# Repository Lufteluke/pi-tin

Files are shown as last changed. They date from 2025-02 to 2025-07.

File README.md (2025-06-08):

# Pi Tin

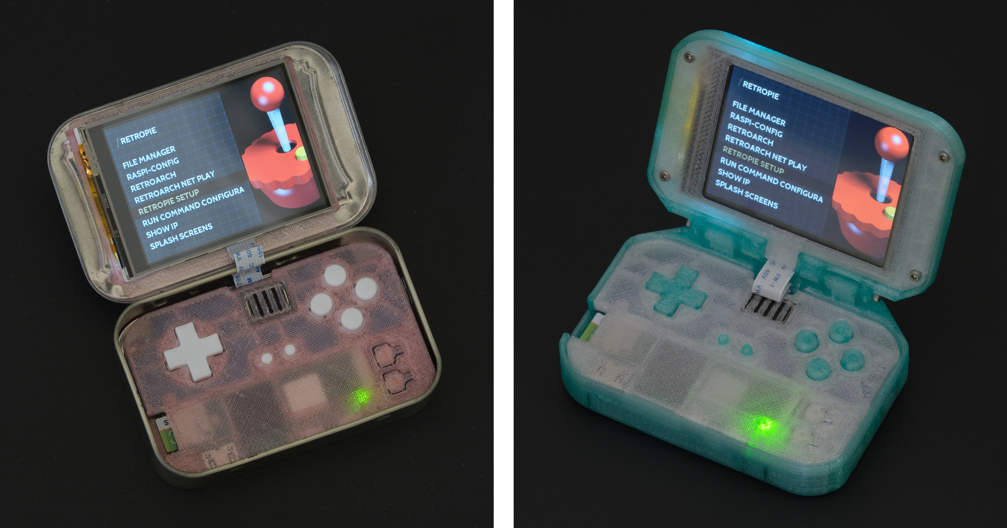
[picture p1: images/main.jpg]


Pi Tin is an open source retro gaming device designed around the Raspberry Pi Zero 2 W and a 2.8" 320x240 TFT display, the largest readily available size that will fit into an Altoids tin. The Pi Zero 2 W is capable of emulating most SNES, GBA, PS1, Genesis/Megadrive, and even some N64 games.

Pi Tin's gamepad uses the exact same Alps tactile switches and elastomer membrane design used in the Gameboy Advance SP and DSi to achieve superior button feel over designs using conductive rubber buttons or bare tactile switches. It features a soft power button to turn on or safely shut down the system with a single press, and is designed to be safe to use while charging and compatible with all USB-C cables and chargers. The battery lasts for up to 5 hours of gaming <small>(tested on 3D printed case option - 2000mAh battery)</small>.

Building a Pi Tin requires a Raspberry Pi Zero 2 W, two custom PCBs, some 3D printed parts, and a few other components which are readily available from distributors. The PCBs require advanced soldering skills and ideally both a hot plate and hot air station to assemble by hand. We are working on making kits with assembled PCBs available to purchase.

Shown below are Rev. 2 PCBs, manufactured by [PCBWay](https://www.pcbway.com/). PCBWay reached out to sponsor this project and I was excited to work with them as I have used PCBWay before at work and have been consistently satisfied with their customization options, turnkey parts sourcing ability, and very responsive customer support. The quality of PCBs they delivered here was excellent as always.

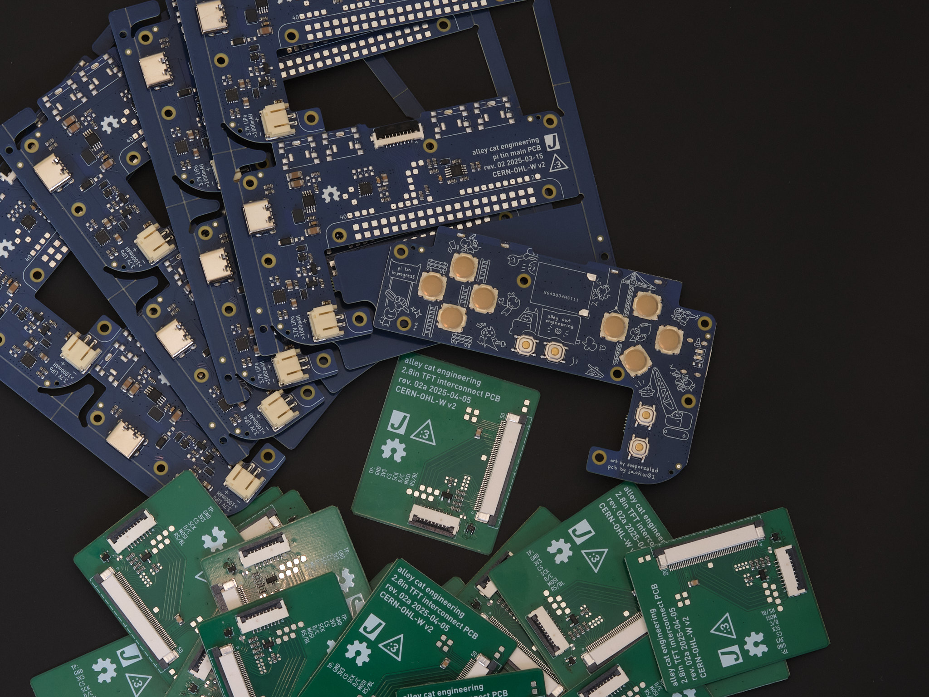
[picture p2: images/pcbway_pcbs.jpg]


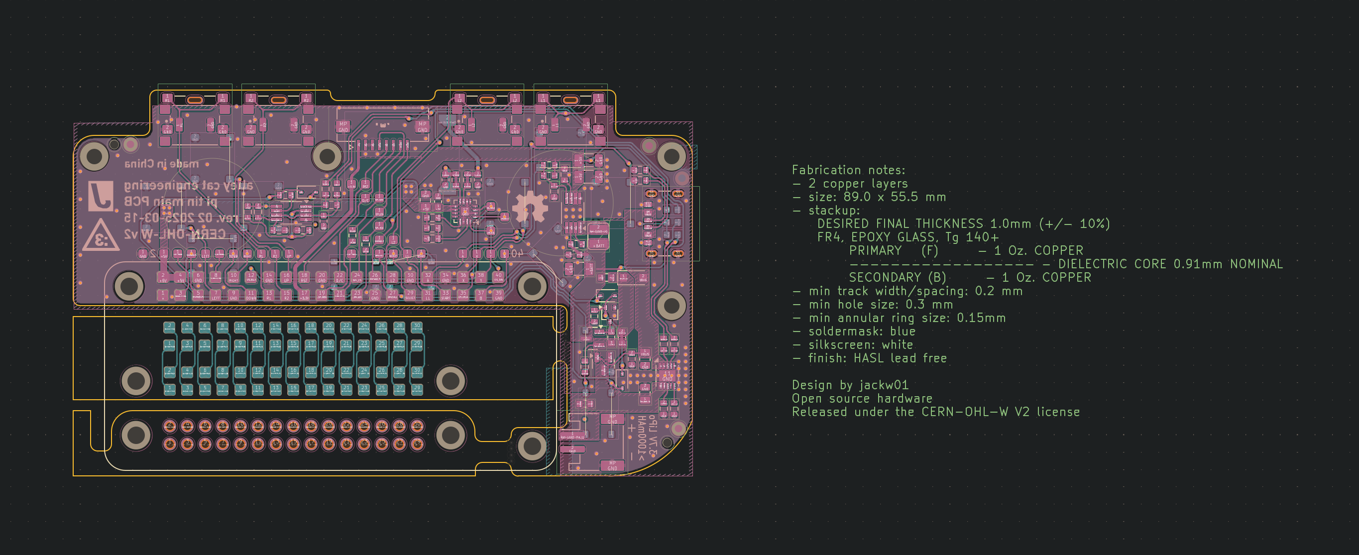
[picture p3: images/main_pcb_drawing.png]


[Main PCB Schematic as PDF (Rev. 2)](pcb_main_r2/pi_tin_main_pcb_r2.pdf)

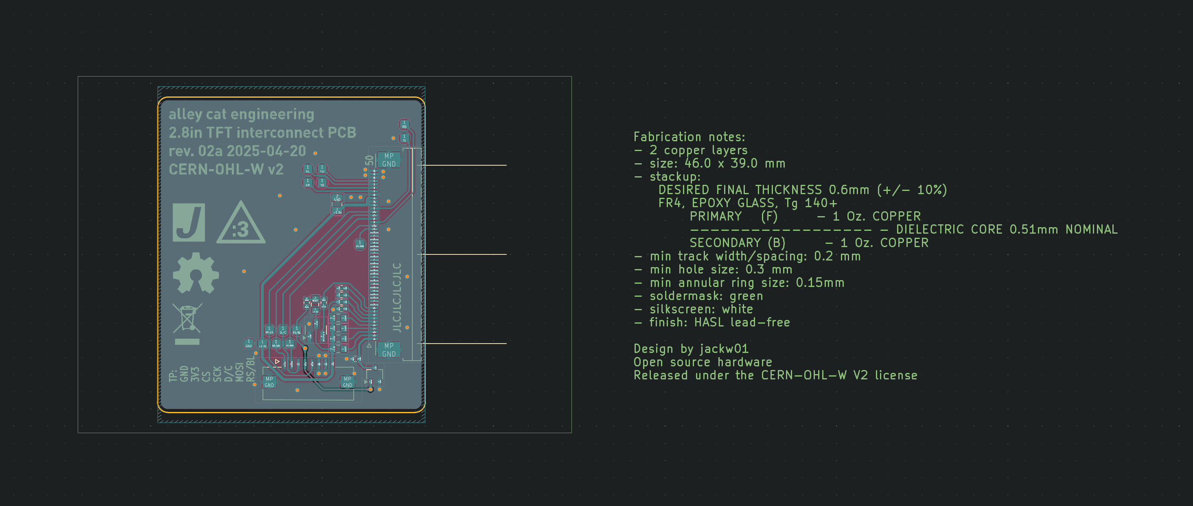
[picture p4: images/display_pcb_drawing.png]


[Display PCB Schematic as PDF (Rev. 2a)](pcb_display_r2a/pi_tin_display_pcb_r2a.pdf)

*Note 2025-06-07: Main PCB files have been updated with the practice boards included in the kits. Display PCB files have been updated to revision 2a with minor component changes and brightness control support. Previous revision files are in the old folder.*

*Note: Most other photos in this guide show Rev. 1 PCBs.*

## build options

Pi Tin can either be built with a 3D printed clamshell case (93 x 66 x 26.5mm) or built to fit inside an Altoids tin.

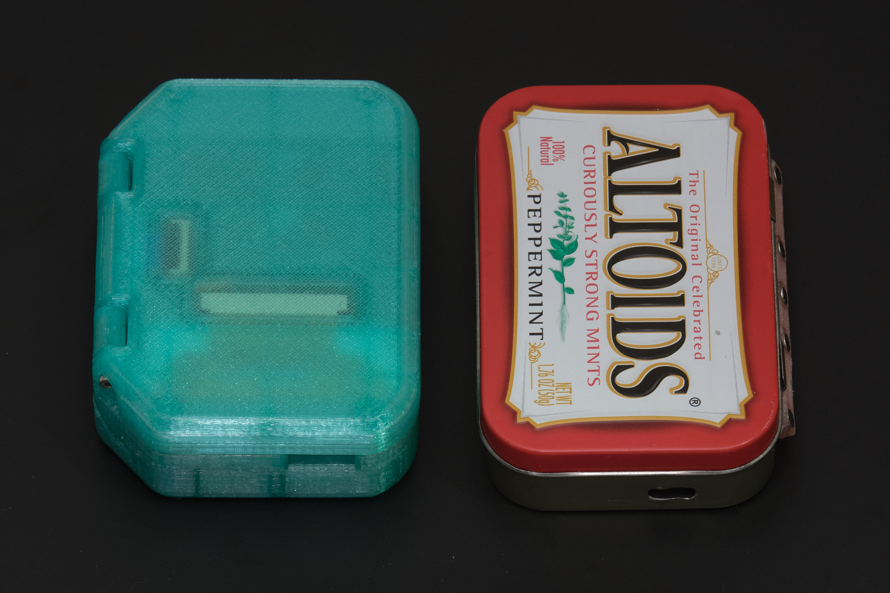
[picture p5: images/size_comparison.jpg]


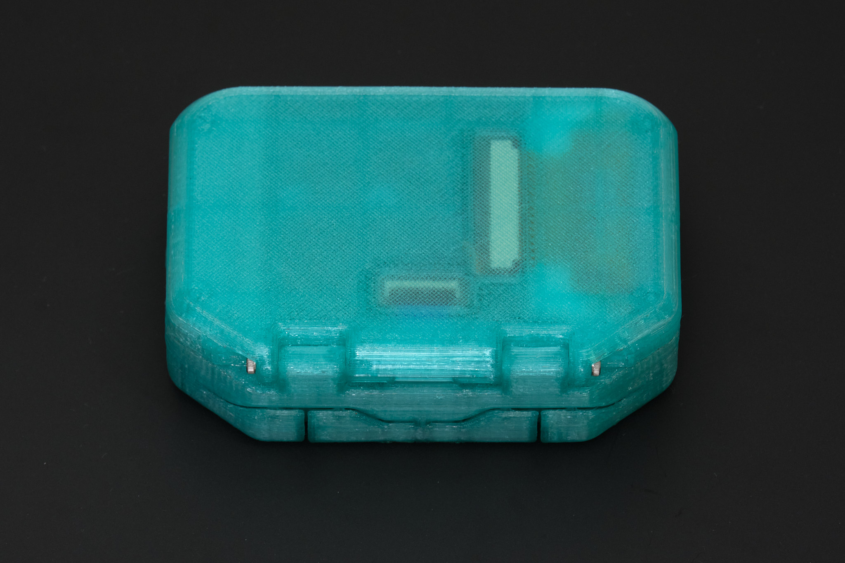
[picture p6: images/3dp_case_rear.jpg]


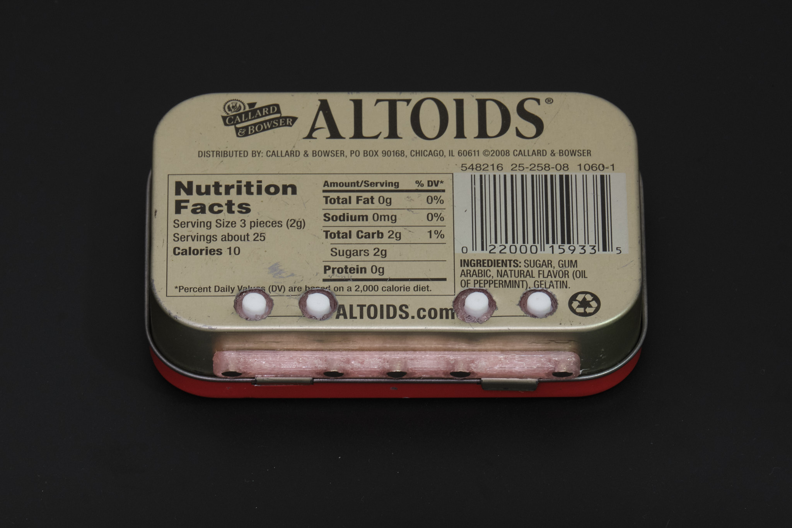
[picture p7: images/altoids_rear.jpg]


The Altoids tin build option is more difficult than the 3D printed case option; it requires additional tools and experience using them. It has poor ergonomics due to the constraints of building inside an Altoids tin and the battery capacity is 40% lower than the 3D printed case version. We strongly recommend the 3D printed case option for these reasons.

**Important: Read through all the instructions thoroughly before building. This is an intermediate level project and we don't recommend attempting it without prior electronics kit building experience.**

Build instructions for both options start with the [hardware build guide](./hardware_build).

## license

The source files for this project are located at [https://github.com/jackw01/pi-tin/](https://github.com/jackw01/pi-tin/).

The PCB schematics, layouts, and Gerber files and the 3D CAD files for this project are released under the CERN Open Hardware Licence Version 2 - Weakly Reciprocal (CERN-OHL-W V2). The files in the `software` directory are in the public domain, free of copyright restrictions. The text, photographs, and illustrations on this website may not be reproduced without permission.

## mintypi disclaimer

We are aware of the existence of MintyPi; our main motivation for building this project was that MintyPi is no longer possible to build as it relies on proprietary parts that are not sold anymore. MintyPi was a closed-source commercial product and it was not released under a license limiting or requiring attribution for derivative works. The creators did not release a schematic of the custom PCBs or even documentation of what drivers/software were installed on their prebuilt SD card image.

## legal disclaimer

Any trademarked product names found on this website belong to their respective owners; this project is in no way affiliated with or endorsed by these companies. Pi Tin is designed to run [RetroPie](https://retropie.org.uk/), which is open source software released under the GPL. The prebuilt RetroPie disk image we provide does not contain any copyrighted ROMs or games. Pi Tin is not designed to enable illegal activity; we do not condone piracy and we will not provide support to anyone looking to obtain copyrighted content. Posting requests for copyrighted ROMs or other piracy-related content on GitHub issues or discussions will result in deletion and a ban.

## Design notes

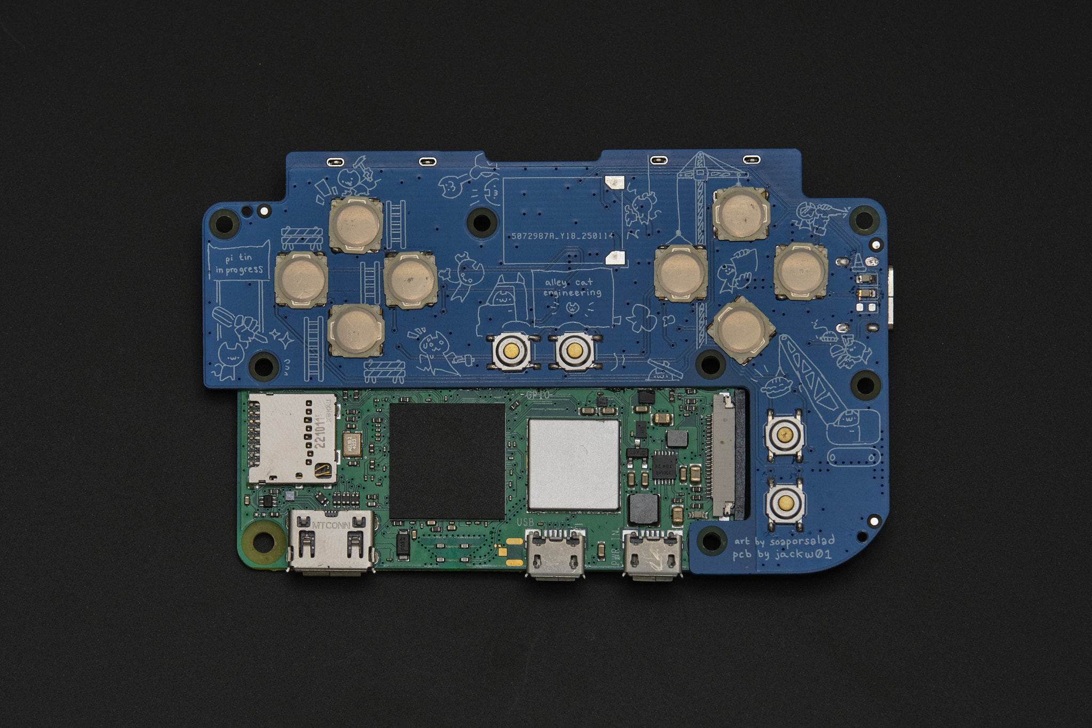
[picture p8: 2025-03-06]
images/main_pcb_1.jpg

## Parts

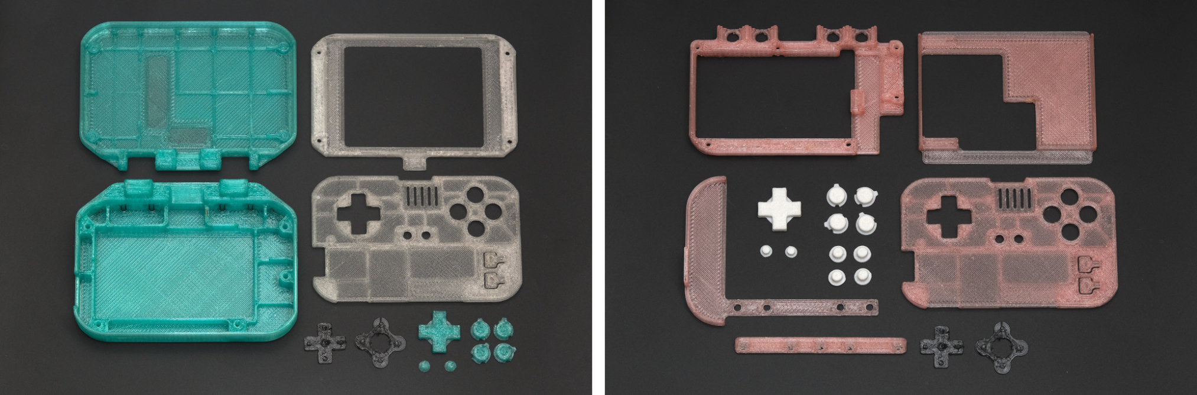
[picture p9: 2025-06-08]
images/3dp_parts.jpg

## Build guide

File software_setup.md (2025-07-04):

# Pi Tin Software Setup

For convenience, we provide a SD card image based on [RetroPie 4.8](https://retropie.org.uk/download/) with all required software installed and configured. This guide assumes you are using the prebuilt image. If not, full instructions for installing the required software on top of a clean install of RetroPie are [here](./full_software_setup).

## 1. install the prebuilt image

Download the Pi Tin prebuilt image [here (2GB zip file)](https://github.com/jackw01/pi-tin/releases/download/v1.1/pi_tin_20250617.zip). Unzip and write the image to a 8GB or larger MicroSD card using [Win32DiskImager](https://sourceforge.net/projects/win32diskimager/), [Raspberry Pi Imager](https://www.raspberrypi.com/software/), or [Etcher](https://etcher.balena.io/).

## 2. set up wifi

After writing the SD card, eject and reinsert it to access the newly created boot partition.

*Note: If using Windows, ignore any popups asking to "scan and fix" or format the SD card.*

Create a file called `wpa_supplicant.conf` in the root directory of the boot partition with the contents below, replacing `SSID` and `PASSWORD` with your network name and password. You can add multiple networks by copying the `network={}` block. If you are outside of the United States, change `country=US` to your country's [ISO two-letter country code](https://en.wikipedia.org/wiki/List_of_ISO_3166_country_codes).

```conf
country=US
ctrl_interface=DIR=/var/run/wpa_supplicant GROUP=netdev
update_config=1

# RETROPIE CONFIG START
network={
    ssid="SSID"
    psk="PASSWORD"
}
# RETROPIE CONFIG END
```

Eject the SD card.

## 3. boot Raspberry Pi and verify functionality

With the display connected, insert the SD card, connect the USB-C cable, and press the power button to power up the Raspberry Pi. If the hardware build and software installation were done correctly, the display should show a black screen at power on, then within 1 minute display the RetroPie splash screen and the EmulationStation launcher. Hold the power button for about half a second and release it. The Raspberry Pi should safely shut down and the display should turn off completely. If the Raspberry Pi does not shut down, it is likely because one or more of the pads is not soldered properly.

## 4. connect via SSH and change password

The Raspberry Pi should automatically connect to your WiFi network within a minute after booting up and you should be able to log in via SSH using the default password `raspberry` (use `ssh pi@retropie.local` in the command line on any computer running Windows 10 or 11, Mac OS, or Linux).

We strongly recommend changing the user password since SSH and SMB are enabled. This can be done by running the `passwd` command on the Raspberry Pi via SSH.

You can also test audio at this point by running `speaker-test -c2` on the Raspberry Pi. You should hear white noise from the speaker.

## 5. using RetroPie

Follow the [RetroPie Getting Started guide](https://retropie.org.uk/docs/Controller-Configuration/) to configure and test the gamepad buttons and load ROMs.

Pi Tin has a dedicated hotkey for RetroPie which is located directly above the power button. **This button should be selected as "Hotkey Enable" during the controller setup process.** The special functions shown below can be used by pressing the buttons while holding down the hotkey.

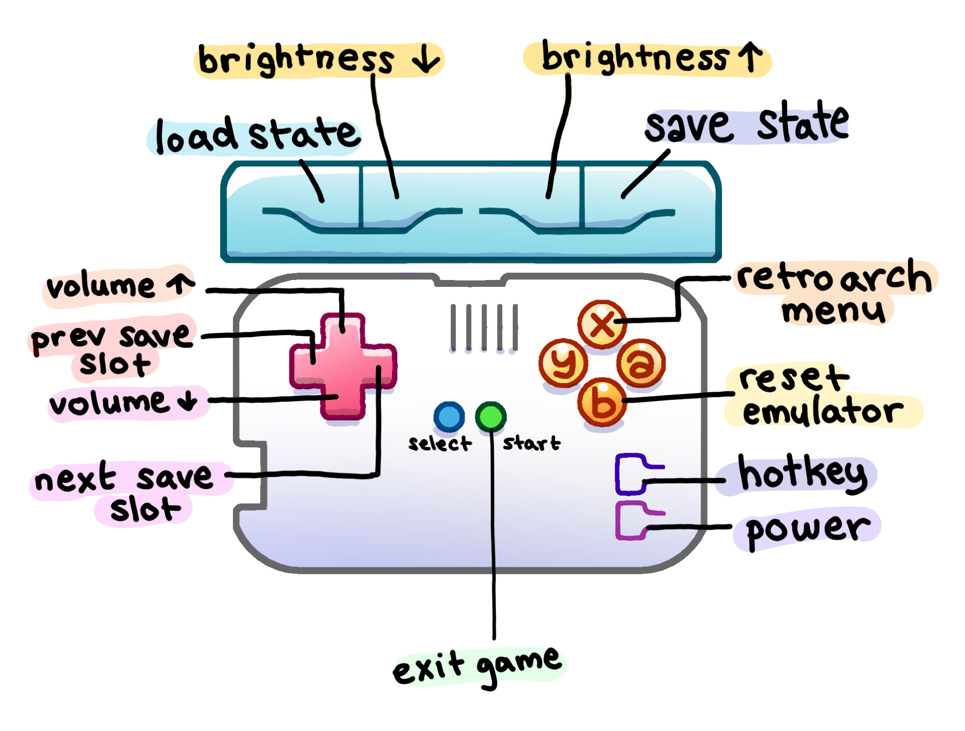
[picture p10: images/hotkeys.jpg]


### configure volume control

The volume control hotkeys must be set up after configuring the controller by manually editing the  configuration file. Log in via SSH and run `sudo nano "/opt/retropie/configs/all/retroarch/autoconfig/GPIOnext Joypad 1.cfg"`. Add these lines at the end of the file to enable volume control using the hotkey and press `Ctrl+X`, then `Y`, then `Enter` to save.

```conf
input_volume_up_axis = "-1"
input_volume_down_axis = "+1"
```

## next steps

Once you have installed and configured RetroPie and verified that the hardware is working, continue to the final assembly guide for your build option.

- [final assembly - 3D printed case version](./3dp_assembly)
- [final assembly - Altoids tin version](./altoids_assembly)

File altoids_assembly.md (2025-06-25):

# Pi Tin Final Assembly (Altoids Tin Version)

**Important: Clean surfaces with isopropyl alcohol before using glue or double-sided tape.**

## 1. complete the Main PCB assembly

Insert three 4x2mm neodymium disc magnets into the rear housing as shown, applying a small dab of cyanoacrylate glue to hold each one in place.

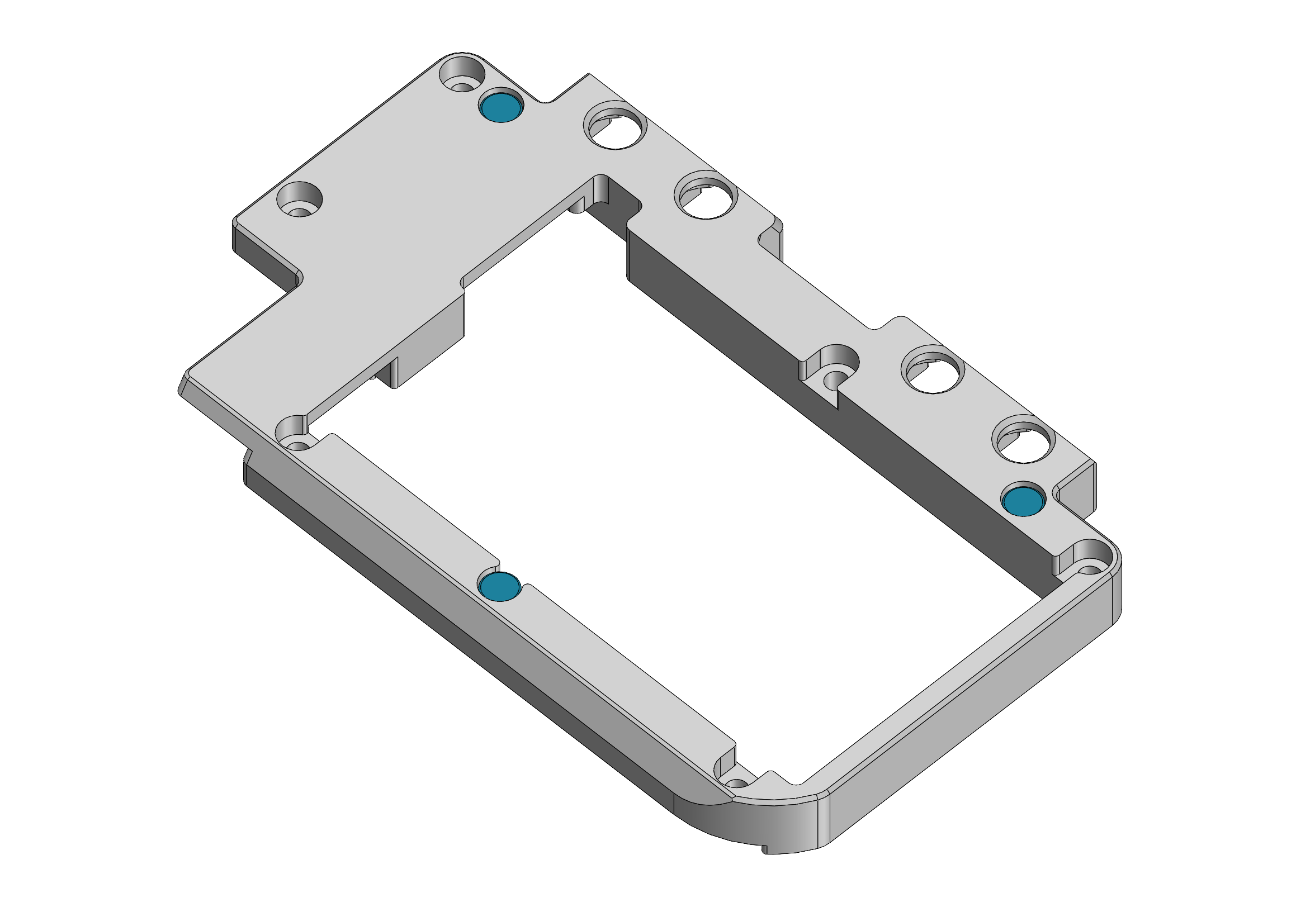
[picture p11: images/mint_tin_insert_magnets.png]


Place the Main PCB onto the assembled front panel and connect the battery, leaving a loop in the battery wires.

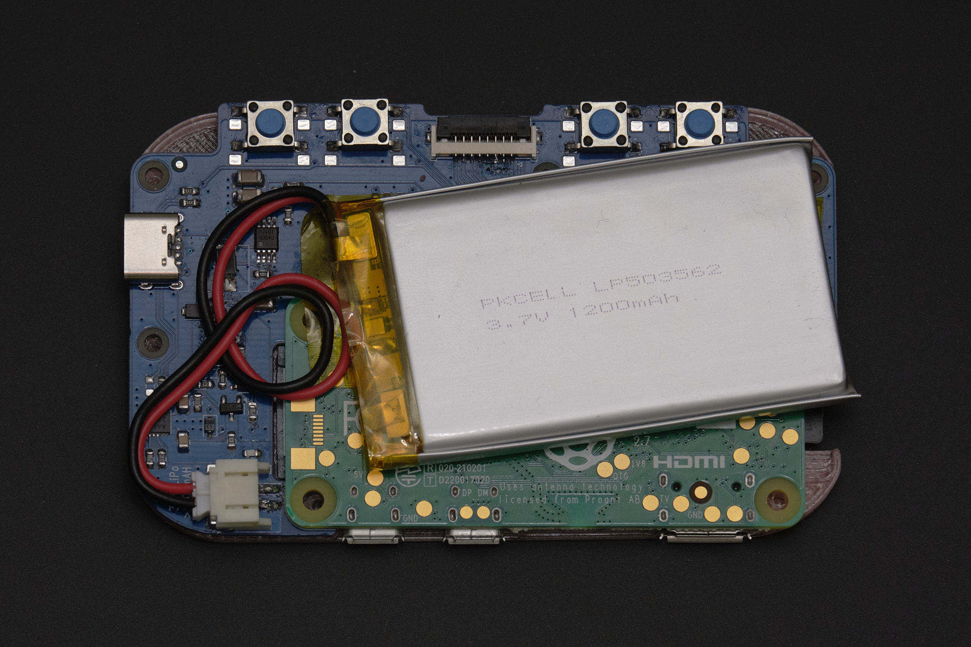
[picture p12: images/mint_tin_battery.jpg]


Insert the four rear buttons into the rear housing, then pick up the front panel and Main PCB together and mate them with the rear housing. The components should fit together closely without applying any force and the battery wires must not be pinched between the rear housing and PCB. Insert six M2x8mm socket head cap screws into the counterbore holes on the rear housing and tighten them in a star pattern. Do not overtighten the screws - stop tightening as soon as no gap is visible between the 3D printed parts and the PCB.

*Note: Some downward pressure is required when tightening the screws for the first time since they are threading directly into plastic.*

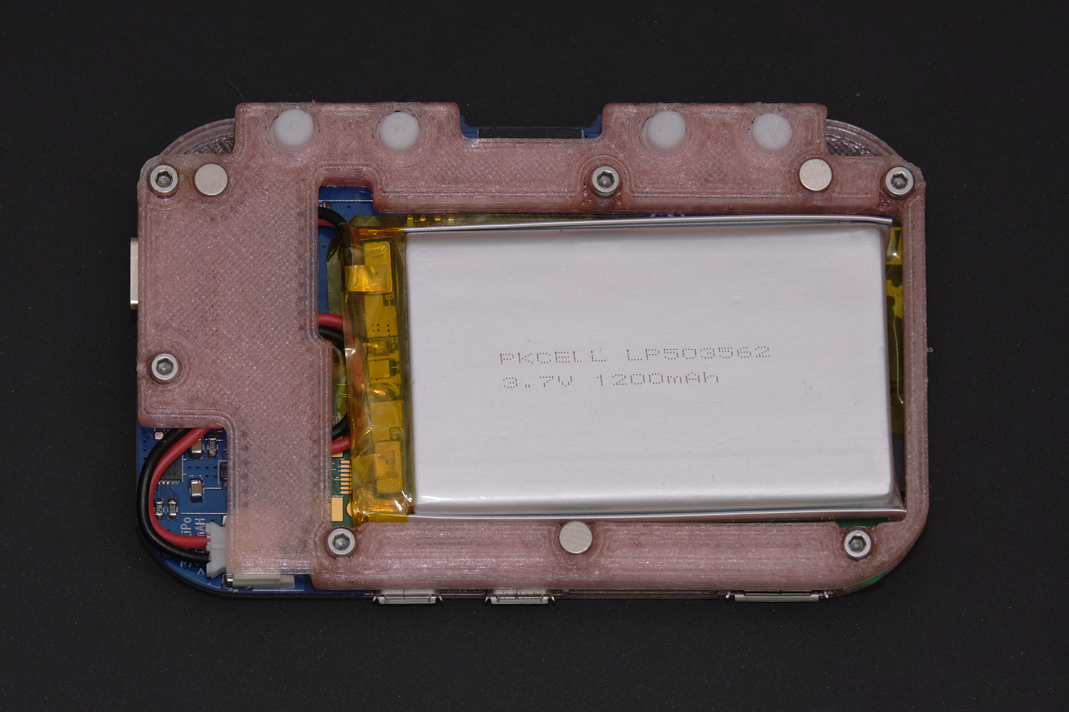
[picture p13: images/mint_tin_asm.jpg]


Check that the buttons on the front panel are not sticking. If they are, it is likely due to misalignment of the 3D printed membrane or defects on the 3D printed parts that need to be trimmed off.

Apply two 6x10mm pieces and one 18x10mm piece of EPDM foam tape in the locations highlighted in blue below to cushion the battery and keep the assembly centered inside the mint tin.

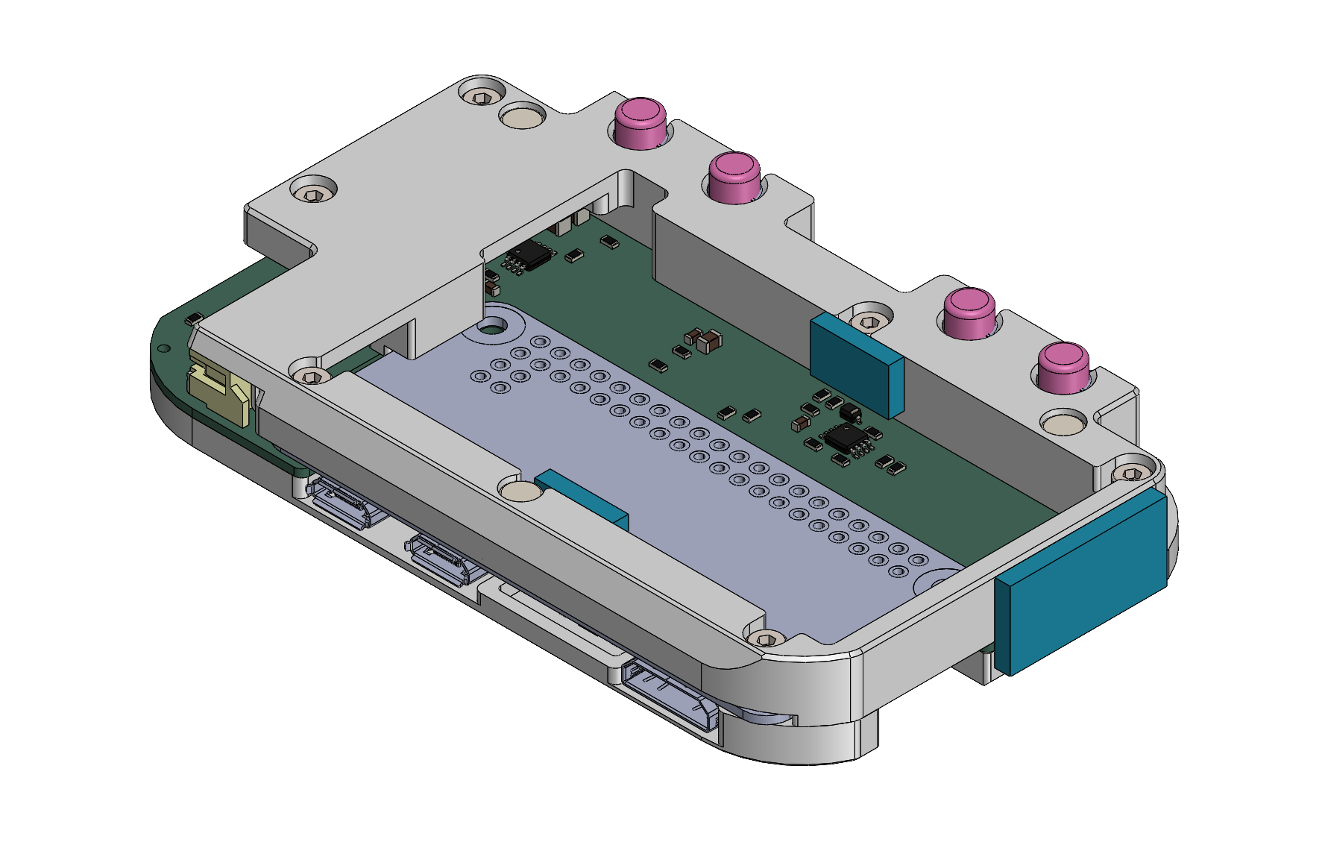
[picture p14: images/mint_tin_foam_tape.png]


## 2. prepare the Altoids tin

Align the drill guide with the tin as shown and use it to mark locations for drilling holes for the USB port and rear buttons. Mark the center of the holes using a center punch or scribe. Use caution if using an automatic center punch as it will leave large dents in the tin if nothing is placed on the other side of the thin metal.

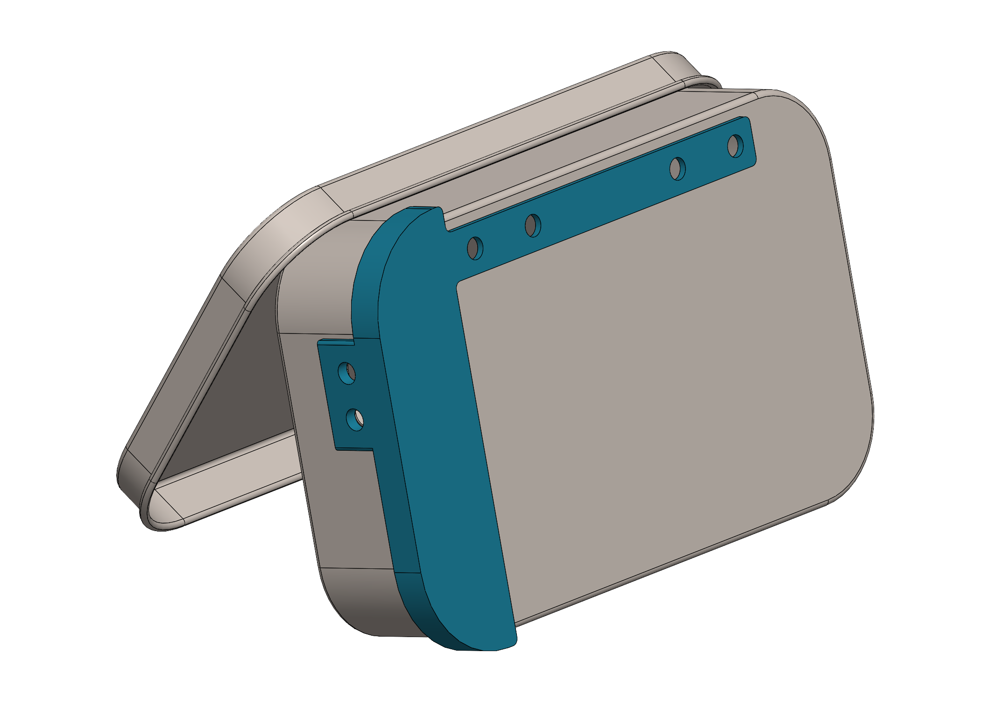
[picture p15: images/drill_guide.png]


Drill all holes with a 1/16in (1.5mm) drill bit. Drill out the four rear button holes to 3/16in (5mm), gradually increasing drill bit sizes and using a sacrificial piece of wood on the other side of the tin to keep the metal from tearing. Drill out the two holes forming the USB port cutout to 1/8in (3mm). Use flush wire cutters to cut out the remaining tab of metal between the holes. Using needle files or a rotary tool, file the USB port cutout to its final shape and debur the edges of the other holes.

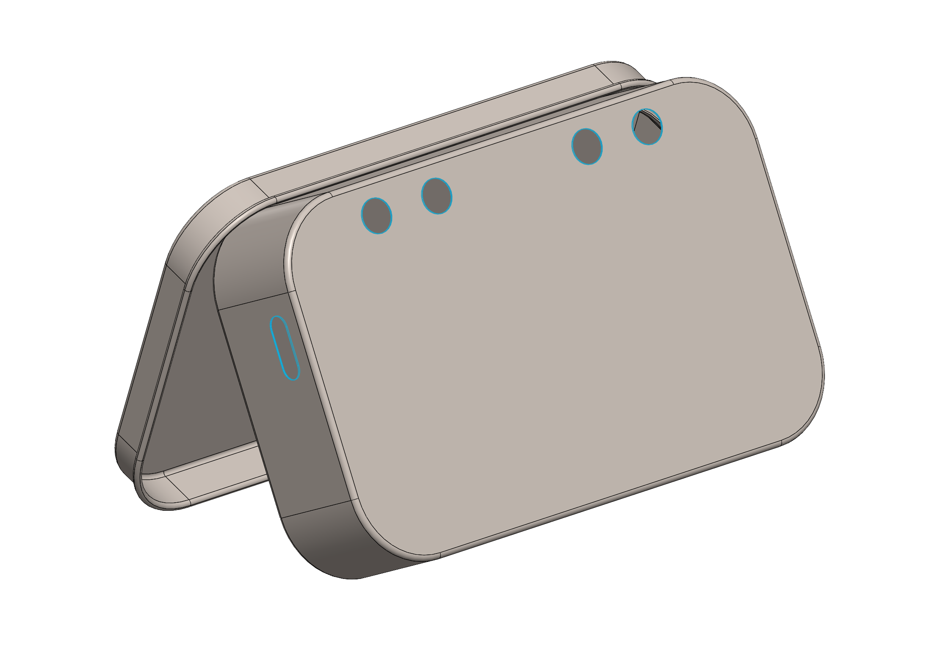
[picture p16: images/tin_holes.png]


Thoroughly clean the tin to remove any metal shavings.

## 3. install the lid stop

Attach the lid stop to the tin as shown using cyanoacrylate glue.

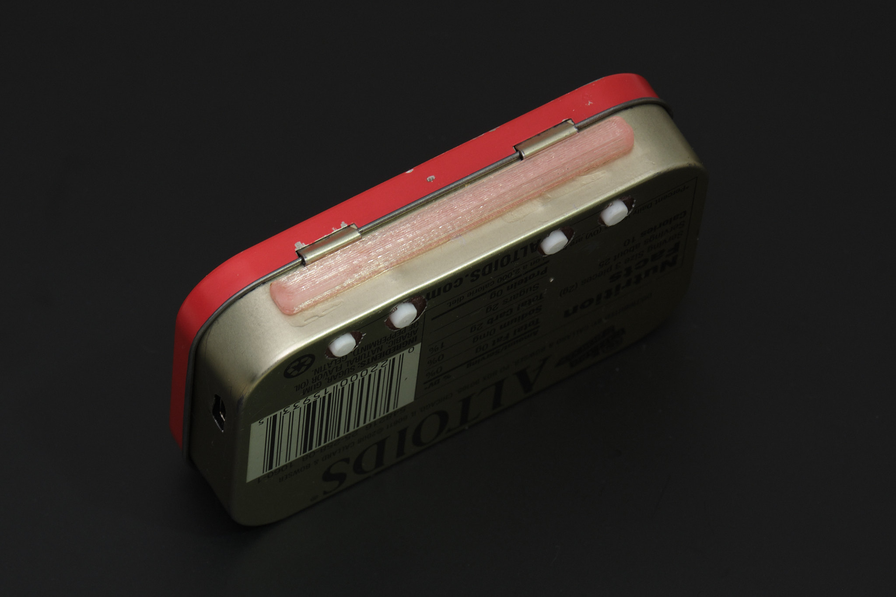
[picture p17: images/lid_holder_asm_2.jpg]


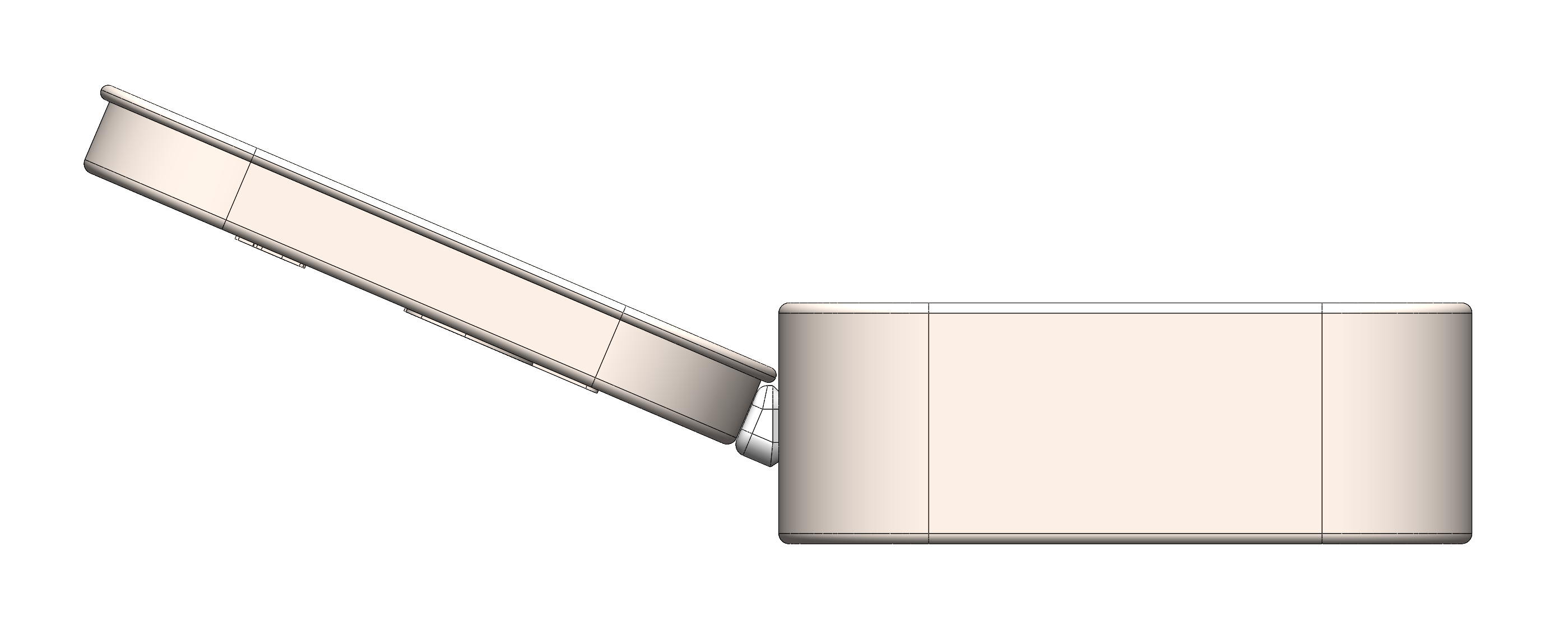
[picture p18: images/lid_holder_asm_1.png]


Insert the 4x2mm neodymium disc magnet into the lid clip as shown, applying a small dab of cyanoacrylate glue to hold it in place.

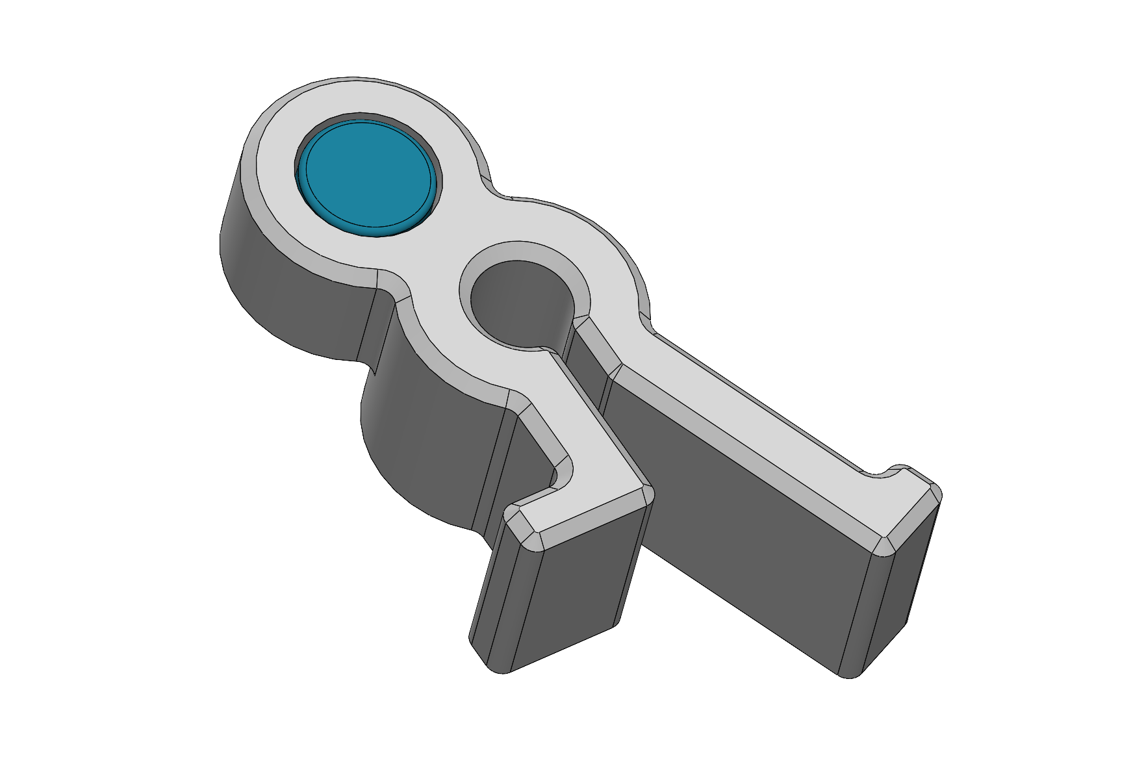
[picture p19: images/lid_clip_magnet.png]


## 4. display

*Note: 3D printed parts in Altoids tin kits will have tape pre-applied. Rev. 1 Display PCB shown, Rev. 2 is smaller but the relative position of the connectors is the same.*

Connect the display to the display PCB if it is not already, following the instructions in the electronics build guide. Use thin double-sided tape or a few tiny drops of cyanoacrylate glue to attach the Display PCB to the rear of the display in its natural resting position, as shown below. The display FPC (orange ribbon cable) should lay flat and must **not** be under any tension. The Display PCB should not overhang the edges of the display module and the display interconnect cable should be roughly centered with the viewing area of the display.

**Rev. 2 PCB**

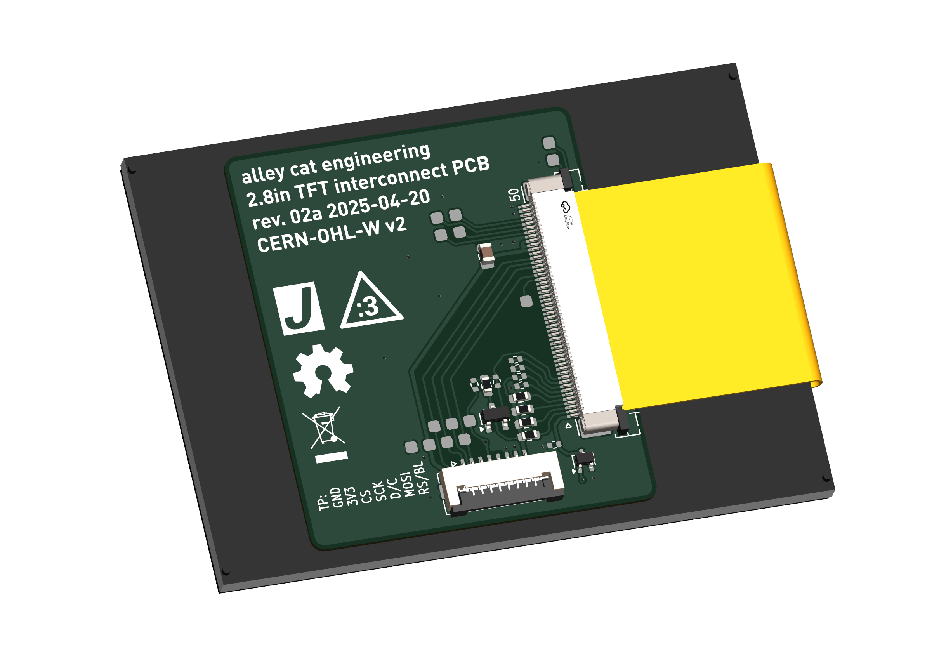
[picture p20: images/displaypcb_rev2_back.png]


**Rev. 1 PCB** (shown from here on out)

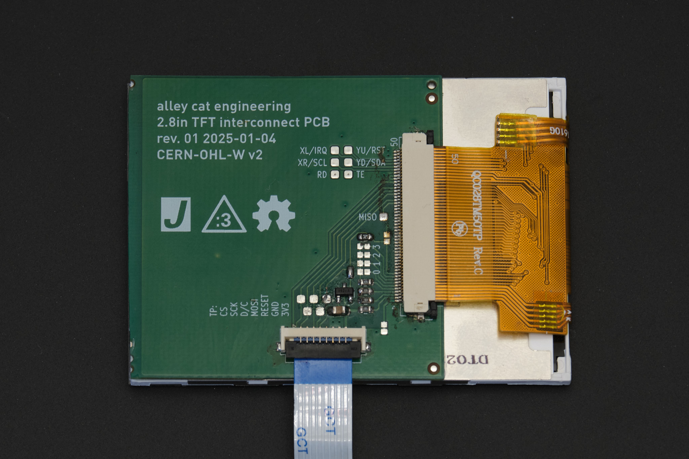
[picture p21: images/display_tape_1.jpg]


Apply thin double-sided tape to the top of the Display PCB or to the corresponding surface on the display mount). Attach the display mount as shown, ensuring that the LCD module is aligned with the two flanges on either side of the display mount. Any vertical misalignment may result in the LCD getting damaged when the tin is closed.

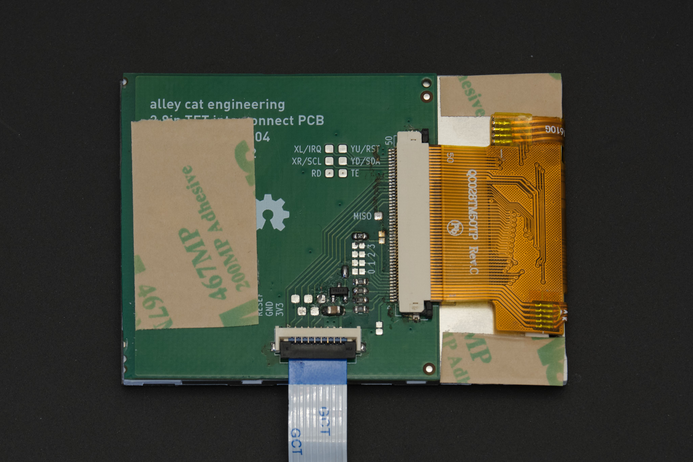
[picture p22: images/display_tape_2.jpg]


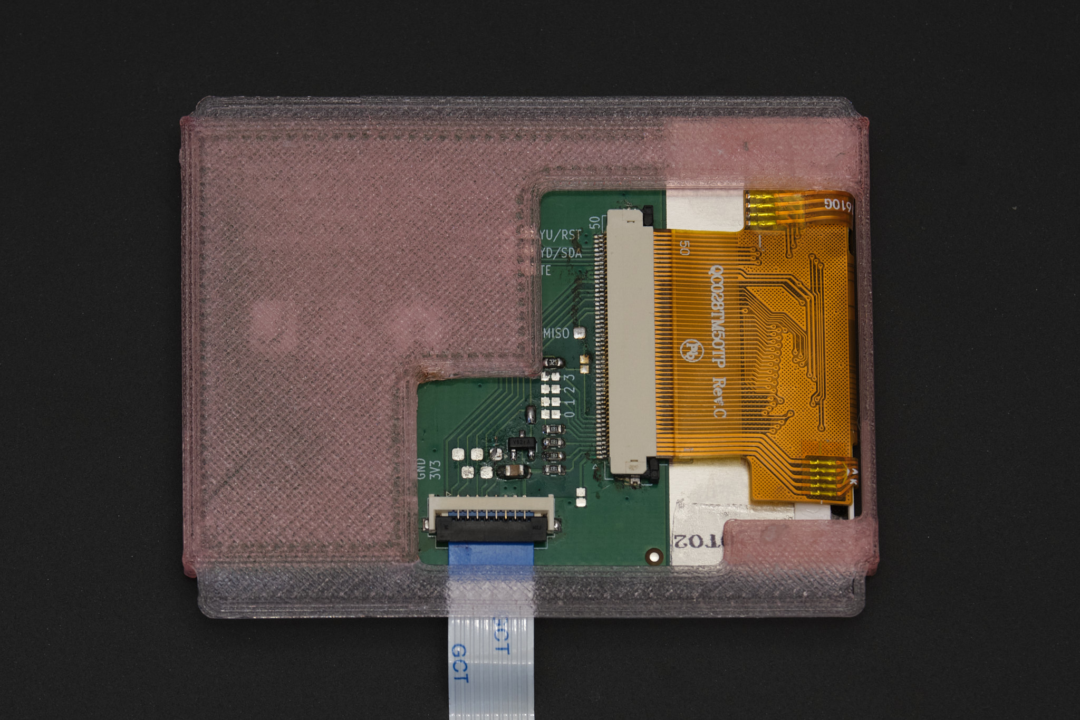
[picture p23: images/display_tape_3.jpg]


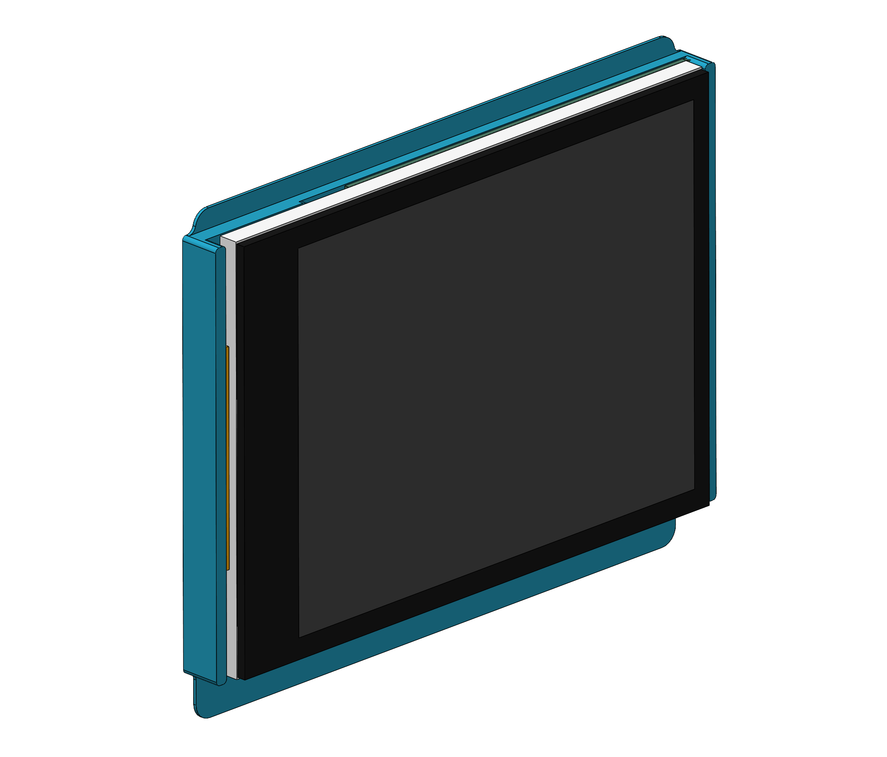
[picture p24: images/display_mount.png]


Apply thin double-sided tape to the display mount. Attach it to the inside of the Altoids tin lid so that the display cable is horizontally centered within the tin.

**Important: Do not glue the display mount into the tin using cyanoacrylate glue. If you do, it will be nearly impossible to access the display cable connector if the display FFC cable breaks or gets pulled out of the connector.**

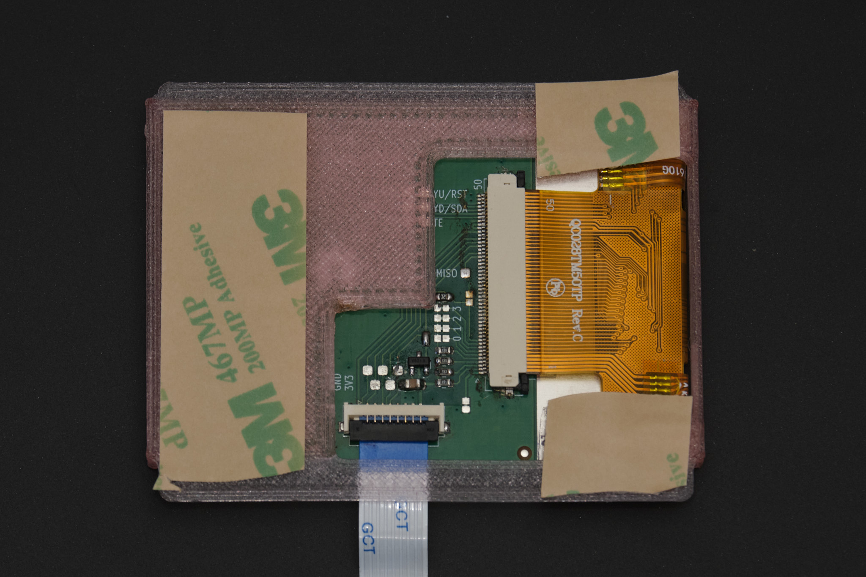
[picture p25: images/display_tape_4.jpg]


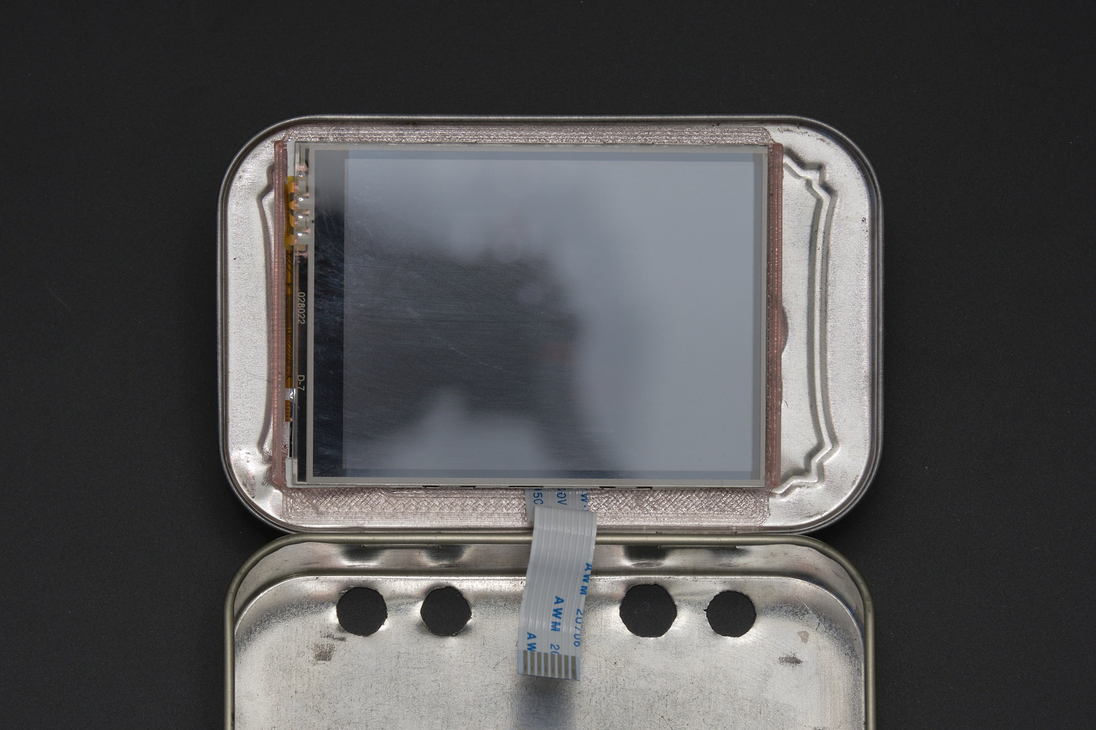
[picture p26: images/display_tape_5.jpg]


**Note: When installed correctly, the display module will appear off center. This is intentional and the viewing area of the display will be centered as shown below.**

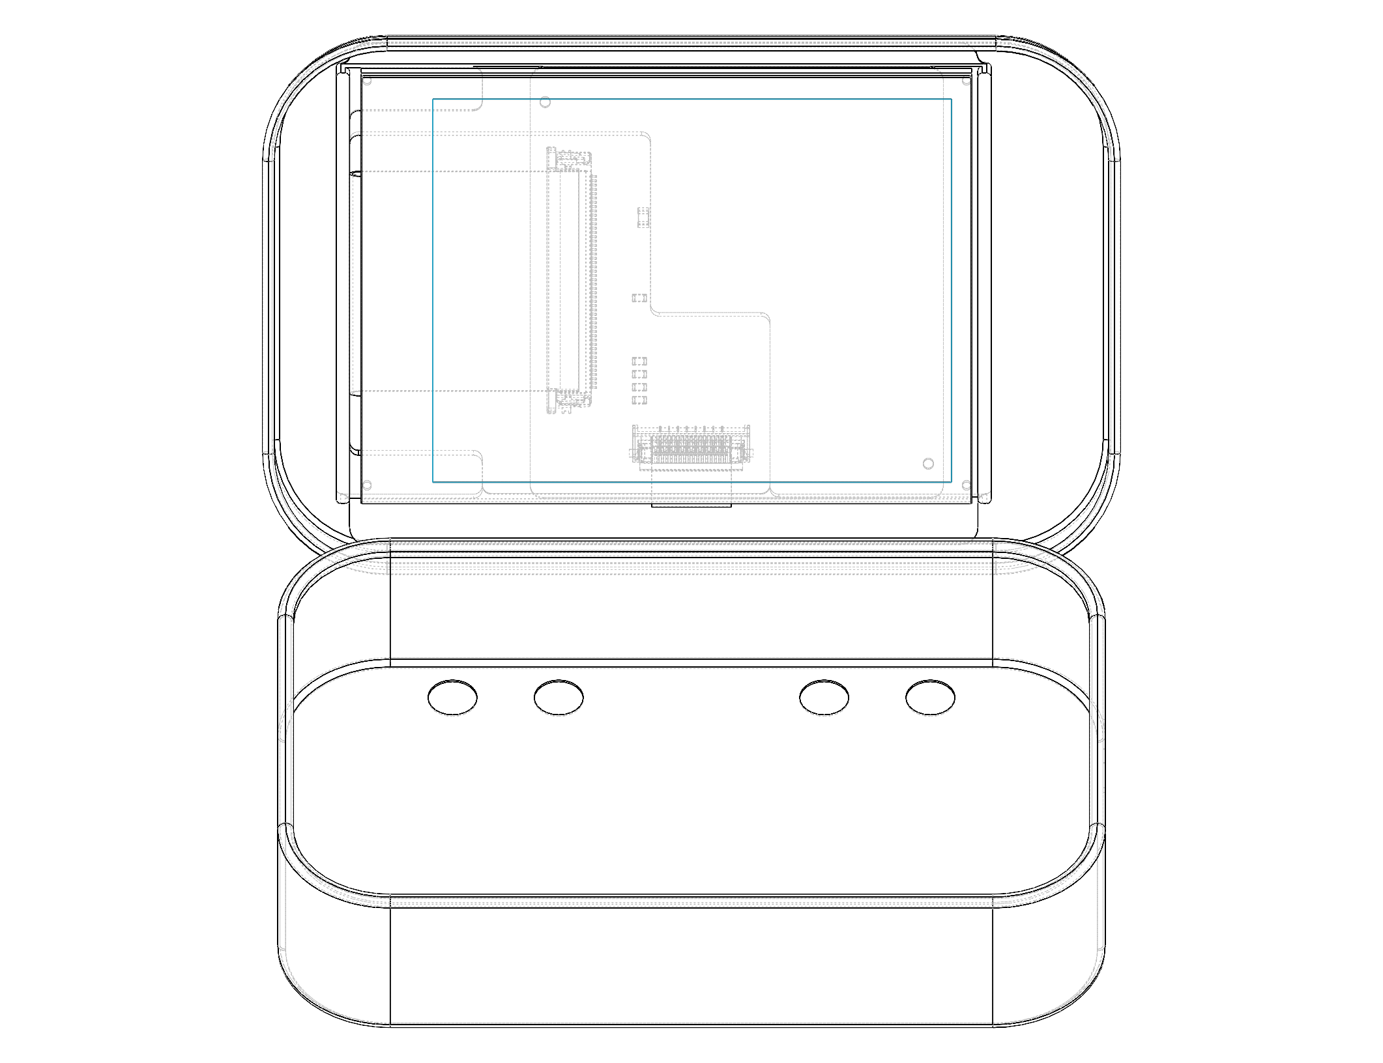
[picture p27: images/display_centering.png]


## 5. final assembly

Connect the display cable to the Main PCB following the same steps used to connect it to the Display PCB. You may need to use tweezers to reach the locking flap on the connector. Insert the Main PCB assembly into the Altoids tin. It is easiest to insert the bottom edge (Raspberry Pi side) first at an angle and then tilt the assembly into place. Check that the rear buttons and USB port line up with the cutouts and that the Main PCB assembly is sitting flush with the base of the tin. Check that the tin is still able to close, making sure that the display cable folds into the space between the front panel and the display instead of being pinched between the display and the tin.

The lid clip is designed to hold both the Main PCB assembly and lid of the tin in place, so the rear buttons can be pressed without holding down the front panel and the Pi Tin can be used upside down. The lid clip attaches to the edge of the tin as shown and can be stowed in the space to the right of the display when not in use.

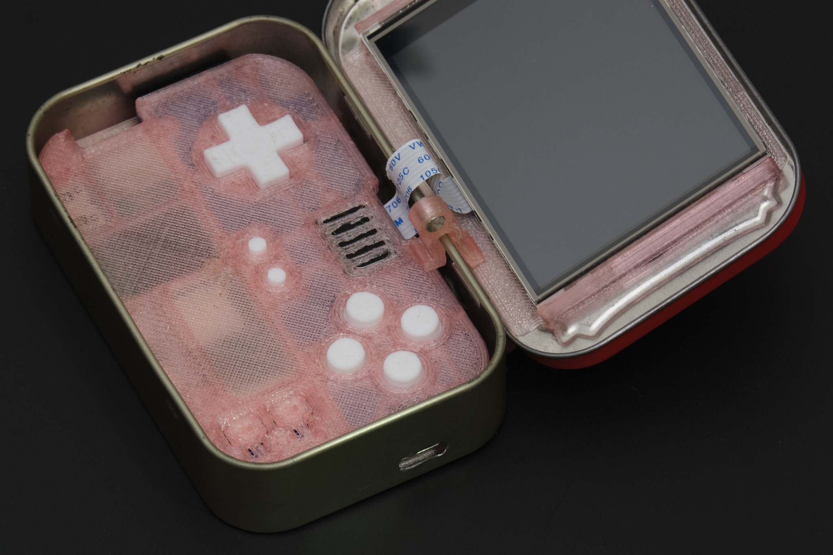
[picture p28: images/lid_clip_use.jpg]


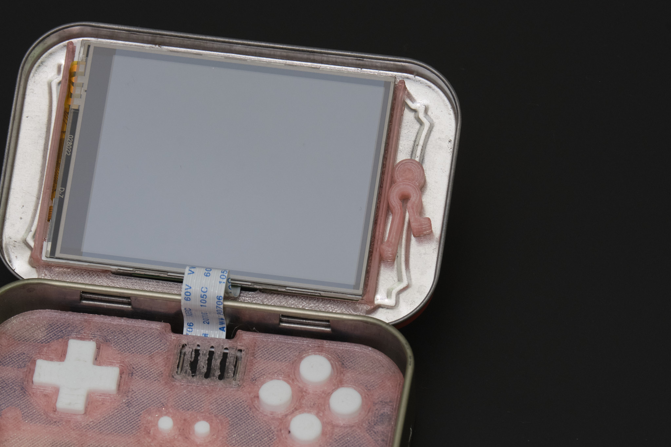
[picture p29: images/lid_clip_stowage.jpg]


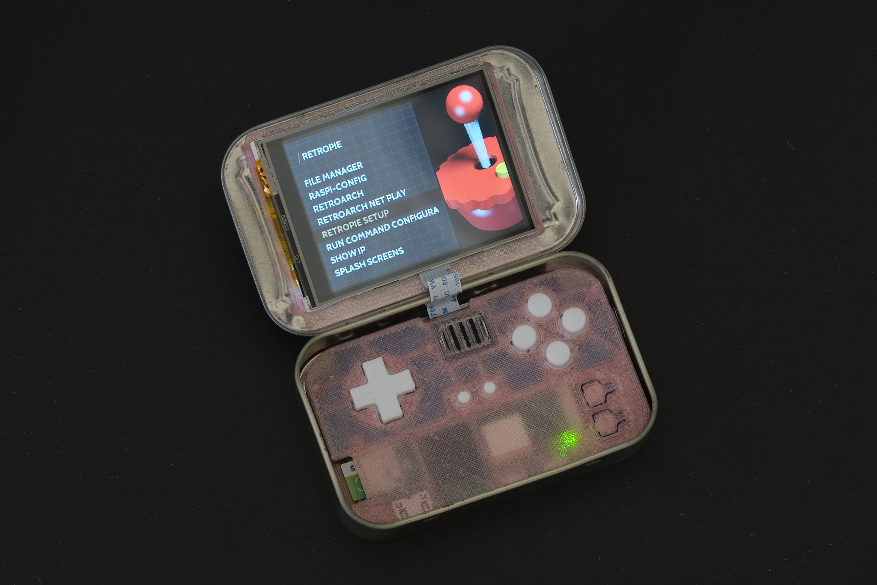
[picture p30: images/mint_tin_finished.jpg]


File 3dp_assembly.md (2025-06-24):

# Pi Tin Final Assembly (3D Printed Version)

## 1. test fit the PCB

Fit the Main PCB assembly into the lower case by inserting the PCB at an angle, USB port side first, and tilting it into place. Loosely insert M2x12 socket head cap screws into the two uppermost screw holes to align the PCB with the case. Verify that all four of the rear buttons can be clicked. If they stick or require excessive force, it is likely because of stringing or blobs of plastic inside the narrow cuts the form the buttons in the 3D printed part. Use fine point tweezers, a craft knife, or dental floss to clear the obstructions.

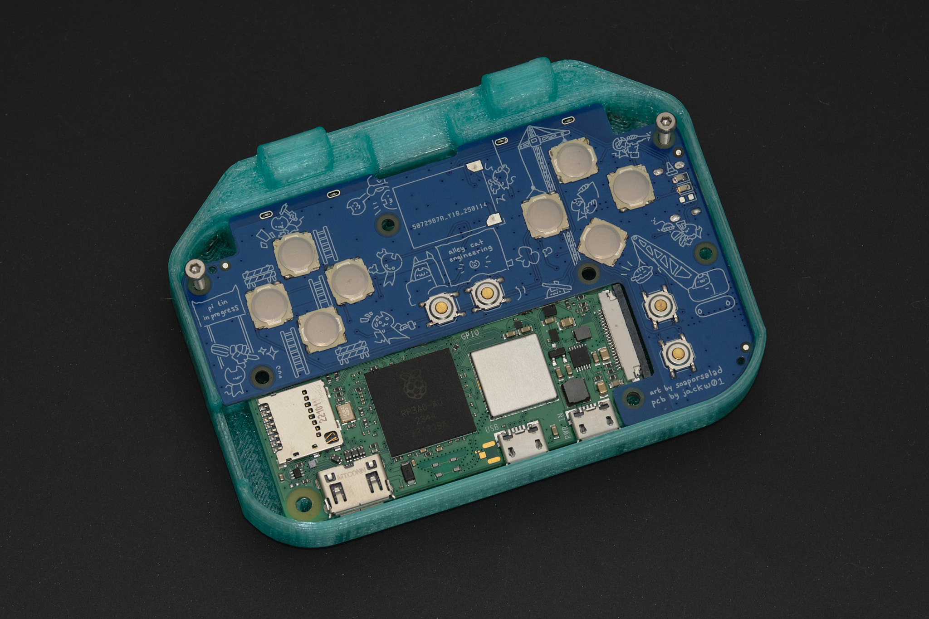
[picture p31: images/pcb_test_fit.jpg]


*Troubleshooting Note: If one of the buttons still gets stuck, it may be due to poor alignment of the Main PCB and Raspberry Pi putting pressure on the tactile switch. In this case, try shimming the PCB by inserting a small piece of paper or tape between the edge of the PCB near the button and the lower case in the next step.*

## 2. lower case assembly

Remove the PCB and screws from the lower case and apply one 6x10mm piece of EPDM foam tape in the location highlighted in blue below to cushion the battery.

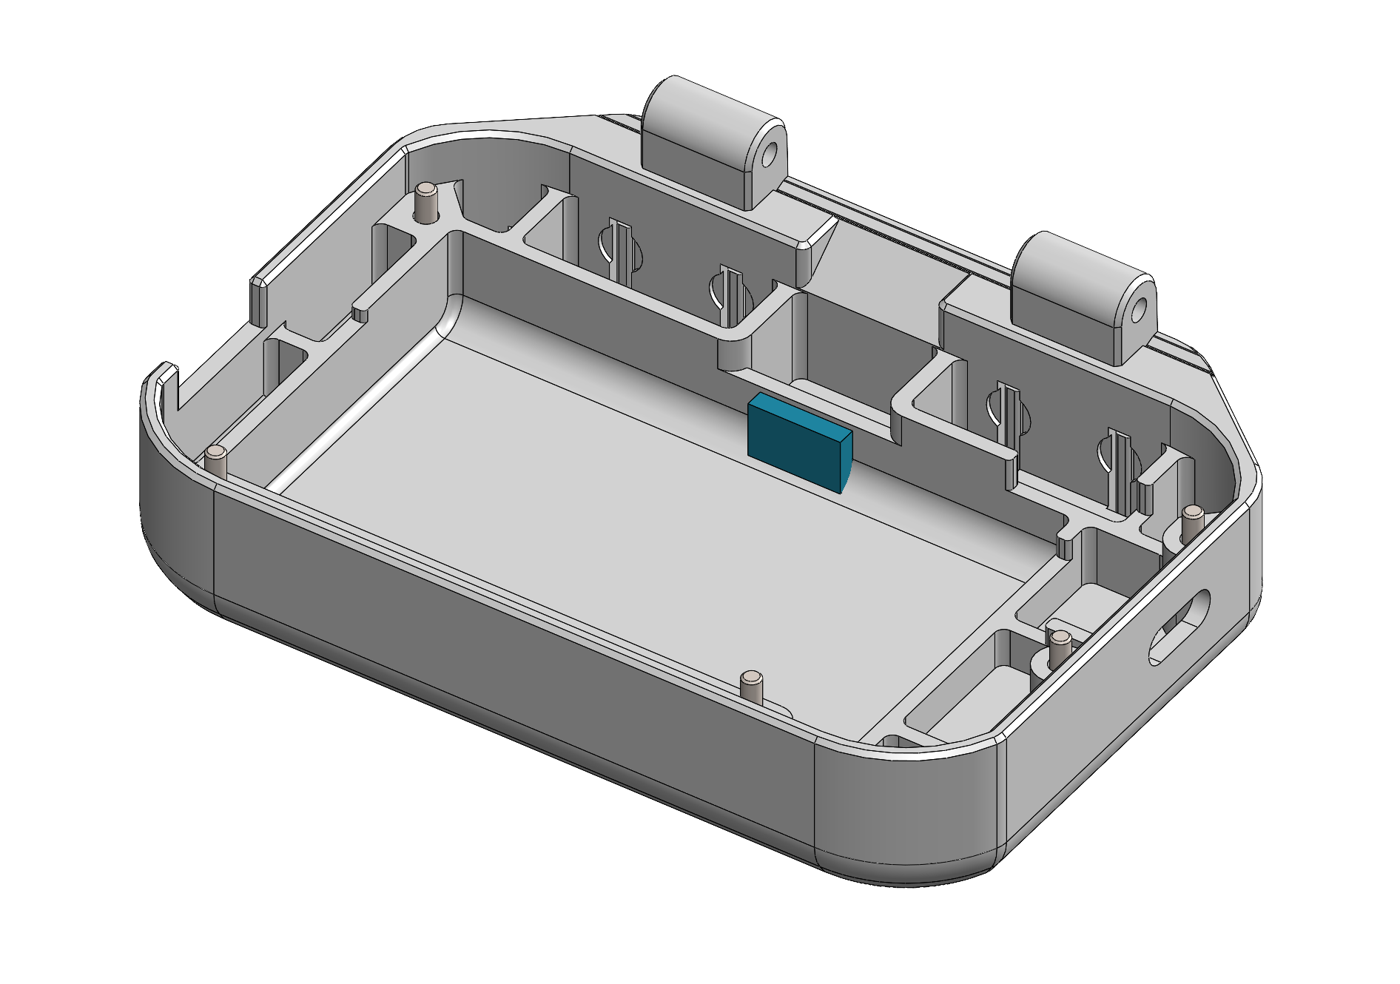
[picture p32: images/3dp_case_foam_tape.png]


Insert the battery into the lower case with the wires facing to the right. Coil the wires as shown and connect the battery to the Main PCB. Disconnect the display cable from the Display PCB (lift the black retention flap on the connector, then remove the cable) and connect it to the Main PCB.

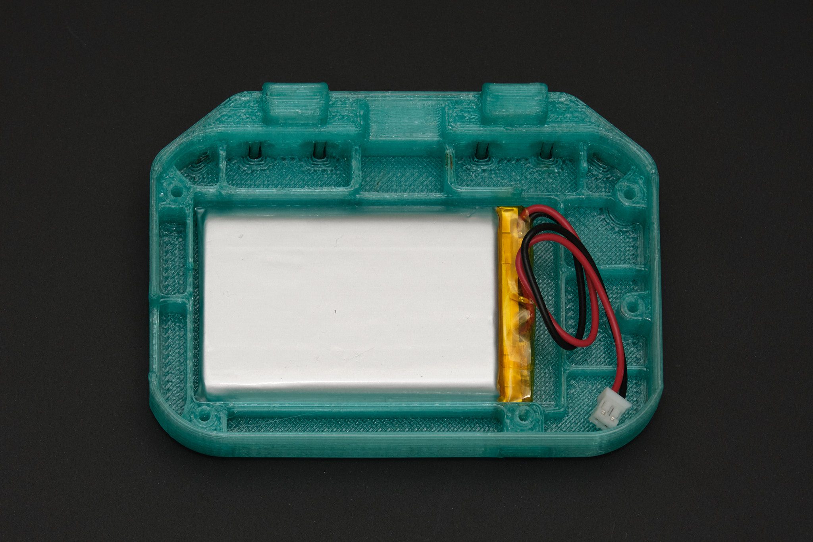
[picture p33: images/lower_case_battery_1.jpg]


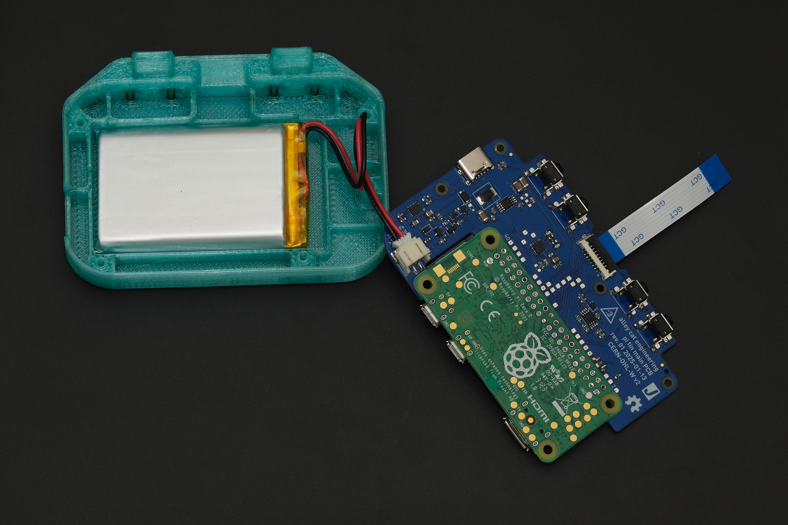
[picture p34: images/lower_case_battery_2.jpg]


Insert the Main PCB assembly into the lower case. The battery wires should stay in the space to the right of the battery and must not be pinched between the PCB and case or battery.

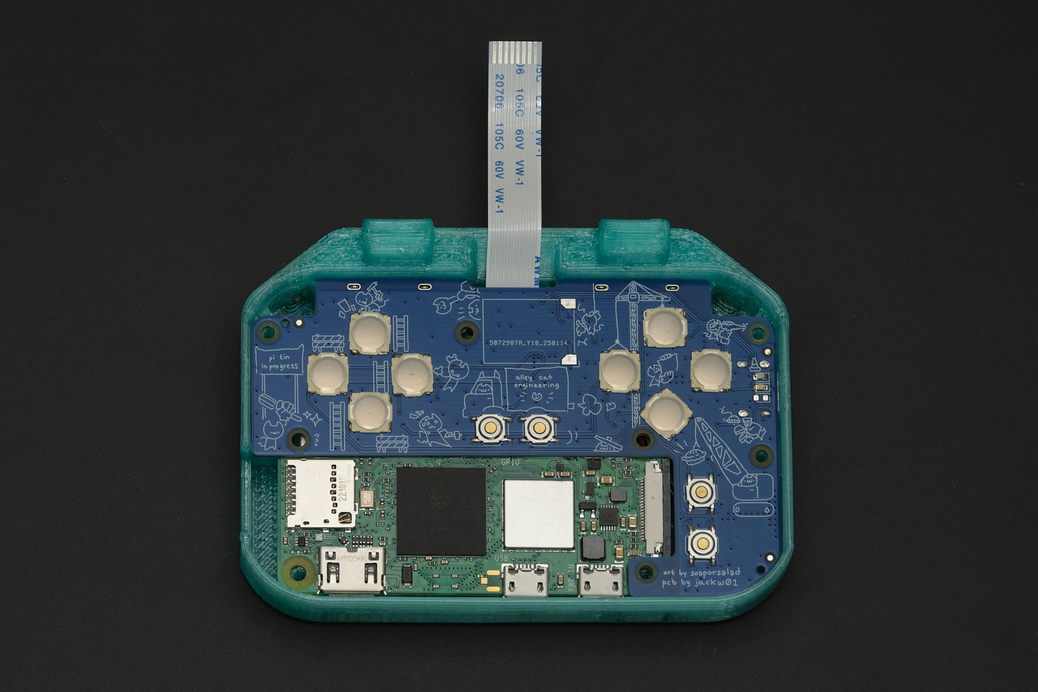
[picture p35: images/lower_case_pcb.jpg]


The Main PCB assembly should ideally fit snugly inside the lower case. If it is loose, plug a USB-C cable into the connector to help with the next step. Turn the lower case assembly upside down and place it onto the assembled front panel. While holding the lower case and front panel together, insert the five M2x12 socket head cap screws into the bottom side of the case and tighten them in a star pattern. Do not overtighten the screws.

*Note: Some downward pressure is required when tightening the screws for the first time since they are threading directly into plastic.*

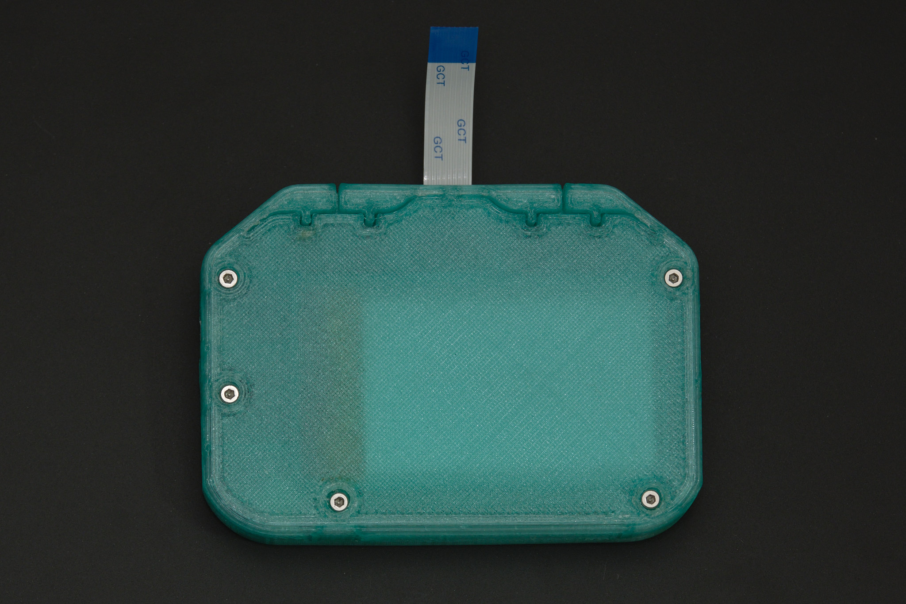
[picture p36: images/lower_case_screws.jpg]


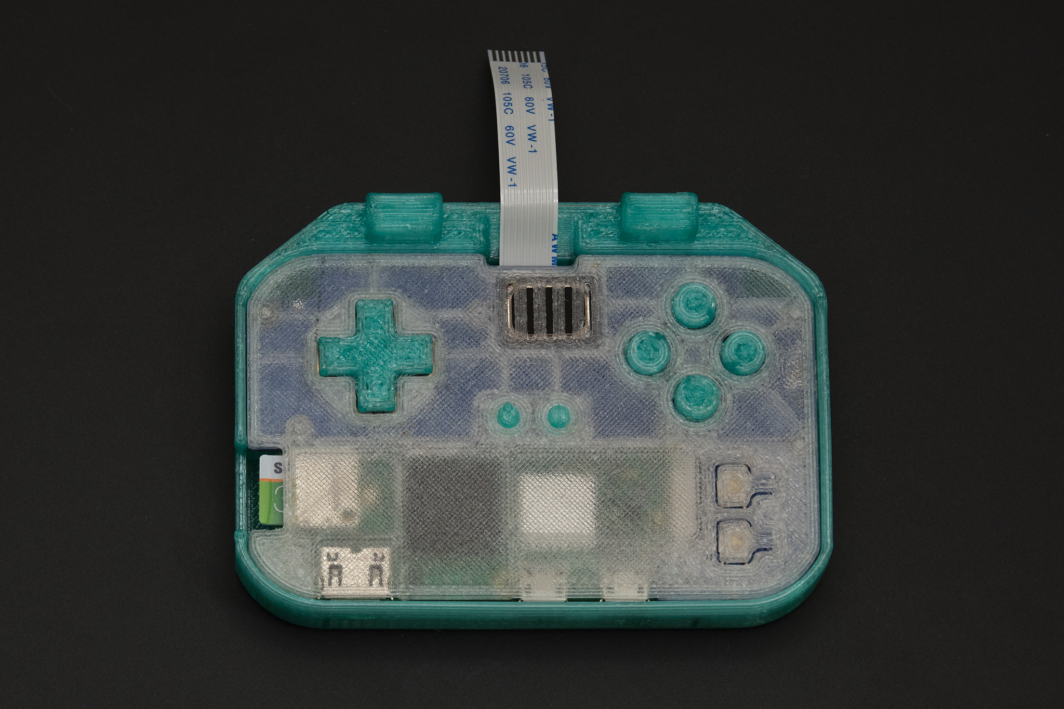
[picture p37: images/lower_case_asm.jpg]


Check that the buttons on the front panel are not sticking. If they are, it is likely due to misalignment of the 3D printed membrane or defects on the 3D printed parts that need to be trimmed off.

## 3. display assembly

*Note: Rev. 1 Display PCB shown, Rev. 2 is smaller but the relative position of the connectors is the same.*

Remove the protective film from the display. Fold the display FPC (orange ribbon cable) over the back of the display and place the display assembly into the display bezel, aligning the display cable connector with the cutout on the bezel. Connect the display cable to the Display PCB.

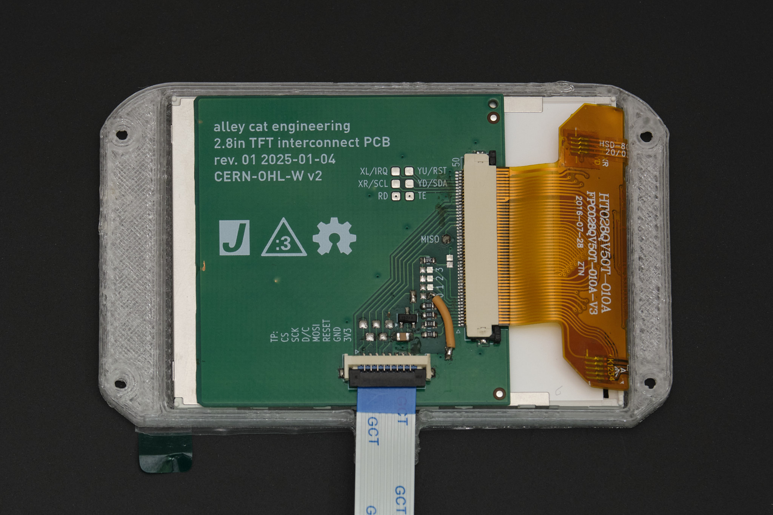
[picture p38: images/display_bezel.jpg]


Place the display housing over the display bezel, aligning the cutout in the housing with the display cable. Flip the assembly over and insert the four M2x4 socket head cap screws into the display bezel. Tighten the screws in a star pattern.

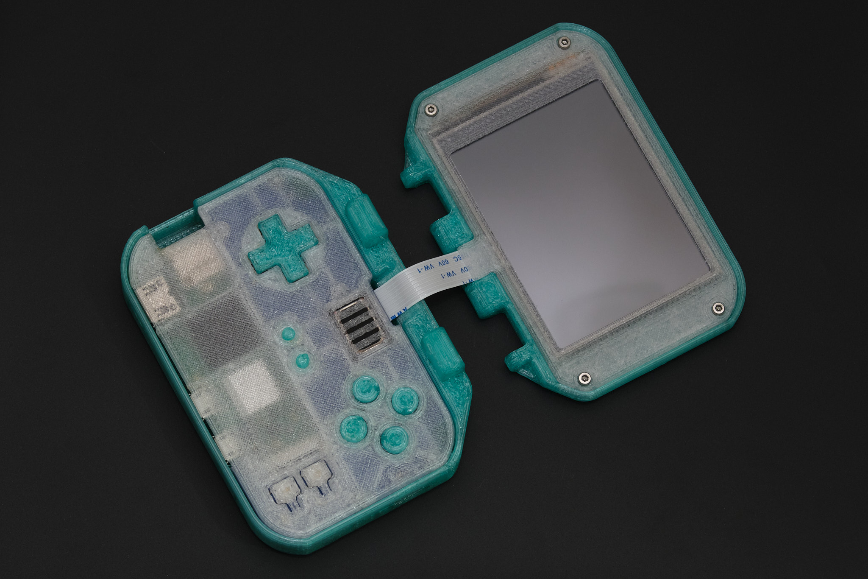
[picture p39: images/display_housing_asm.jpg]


## 4. final assembly

Align the display housing with the mounting points on the lower case, folding the display cable forward as shown. Insert and tighten the two M2x20 socket head cap screws that hold the display hinge together.

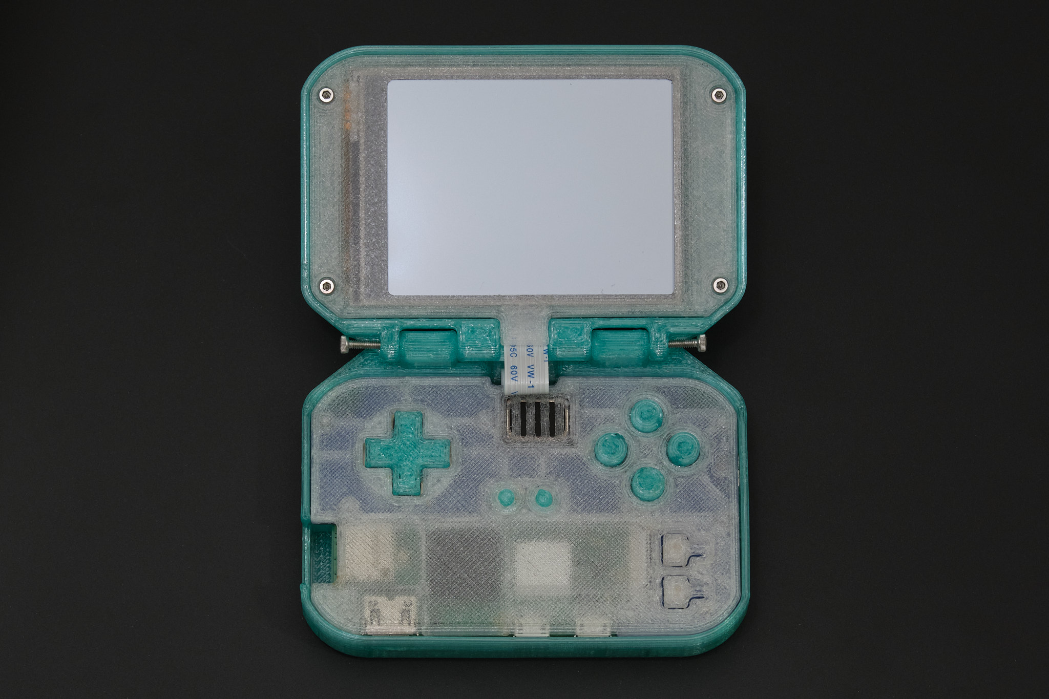
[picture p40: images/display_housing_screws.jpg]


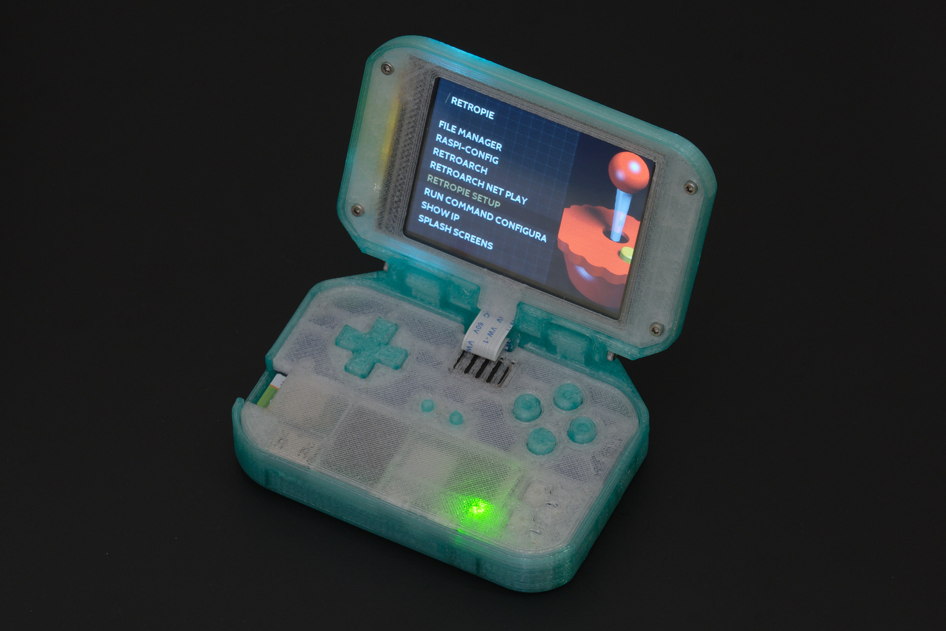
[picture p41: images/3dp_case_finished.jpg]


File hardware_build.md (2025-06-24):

# Pi Tin Hardware

**Important: Read through all the instructions thoroughly before building. This includes the software setup guide and the final assembly instructions for your chosen build option.**

## required parts

- Raspberry Pi Zero 2 W (Pi Zero 1 not tested, and will probably not work)
- Pi Tin Main PCB
- Pi Tin Display Interconnect PCB
- 2.8" ILI9341 TFT display with 50-pin FPC connector ([Adafruit 1774](https://www.adafruit.com/product/1774))
- Micro SD card, 8GB or larger
- speaker ([CUI CMS-151125-076S-67](https://www.digikey.com/en/products/detail/same-sky-formerly-cui-devices/CMS-151125-076S-67/9561097))
- display interconnect cable ([GCT 10-08-A-0050-C-4-08-4-T](https://www.digikey.com/en/products/detail/gct/10-08-A-0050-C-4-08-4-T/22247571))
- 3D printed faceplate
- D-pad, A/B/X/Y, start, and select buttons (either 3D printed or DS Lite buttons)
- 3D printed TPU button inserts/membranes (exact parts needed depend on buttons used)

### for 3D printed case version

- 2000mAH LiPo battery, 8.0x38x60mm ([Adafruit 2011](https://www.adafruit.com/product/2011))
- 5x M2x12 socket head cap screw
- 4x M2x4 socket head cap screw
- 2x M2x20 socket head cap screw
- 3D printed lower case
- 3D printed display housing
- 3D printed display bezel

### for Altoids tin version

- 1200mAH LiPo battery, 5.0x35x62mm ([Adafruit 258](https://www.adafruit.com/product/258))
- Altoids Classic 1.76oz tin (other brands or sizes will not work)
- 6x M2x8 socket head cap screw
- 4x 4x2mm neodymium disc magnets
- 3D printed rear housing
- 3D printed display mount
- 3D printed lid stop
- 3D printed lid clip
- 4x 3D printed rear button
- 3D printed drill guide

## required tools and materials

- soldering iron with narrow conical tip
- solder (63% tin / 37% lead solder, 0.6mm or smaller diameter recommended)
- 2mm thick x 10mm wide EPDM foam tape or similar adhesive-backed foam (included in kits)
- flux pen or paste flux (use rosin or no-clean flux only, not water soluble flux. we recommend [Chip Quik NC191](https://www.digikey.com/en/products/detail/chip-quik-inc/NC191/11480391))
- two binder clips or small spring clamps (such as [Harbor Freight #69375](https://www.harborfreight.com/micro-spring-clamp-set-6-piece-69375.html))
- multimeter with continuity test setting
- 1.5mm hex screwdriver or allen key
- fine point tweezers
- computer with Micro SD card reader

### for Altoids tin version

- drill with 1/16in (1.5mm), 1/8in (3mm), and 3/16in (5mm) drill bits
- needle files, or rotary tool with small abrasive grinding bits
- small flush wire cutters
- wood block that fits inside open Altoids tin, to support it during drilling
- isopropyl alcohol, 91%
- thin double-sided tape (such as 3M 467MP/468MP or Tesa 61395)
- cyanoacrylate adhesive (super glue)

## 3D printing instructions

*Note 2025-06-07: STL files have been updated with some minor changes for manufacturability (including the option to print the A/B/X/Y buttons as one piece), and the Altoids tin display mount was significantly changed for compatibility with the displays that will be included in the kits.*

All parts except the button membranes should be printed in PETG or ABS with 0.2mm or 0.1mm layer height, using either a 0.4mm nozzle with 4 perimeters or 0.6mm nozzle with 3 perimeters. If using 3D printed buttons, they should be printed with 0.1mm layer height. The button membranes should be printed in 95A durometer TPU with 0.1mm layer height. If printing in TPU is not possible, a rigid material can be used, but the buttons will be louder and clickier and the rounded nub on the D-pad membrane will have to be trimmed as it is designed to compress slightly when printed in TPU.

All parts have a flat face and should be printed with this side facing down. All parts should be printable without supports on a well-tuned printer, but we recommend printing the case back and display bezel (3DP case version) or rear housing (Altoids tin version) with the "support on build plate only" option to achieve better quality counterbore holes.

**Important: If using PETG, it is important to dry the filament before printing as these parts have somewhat tight tolerances and stringing or blobbing caused by wet filament can make them unusable.**

STL files for all 3D printed parts can be downloaded [here (ZIP file)](3d/pi_tin_stl.zip). They are organized in folders based on build variant and button type (3D printed or DS Lite buttons). Some parts have "x2" or similar at the end of the filename, which means that multiple copies of that part are required. There are separate versions of the faceplate for opaque and translucent materials - the version for opaque materials has a hole exposing the battery indicator LEDs. The 3D printed A/B/X/Y buttons can either be printed individually or as one conjoined part; STL files for both options are included.

### if using DS Lite buttons

If using DS Lite buttons instead of 3D printed buttons, the TPU button membranes (black) will look different than what is shown in the photos below - there is a different D-pad membrane and four separate cylindrical plugs that fit into the A/B/X/Y buttons. It is necessary to fill the hollow inside of the DS Lite start/select buttons and a STL file is provided for this, but it may be too small to print well on some printers. Filling these buttons with hot glue, epoxy, or silicone will work just as well.

### all 3D printed parts for 3D printed case version

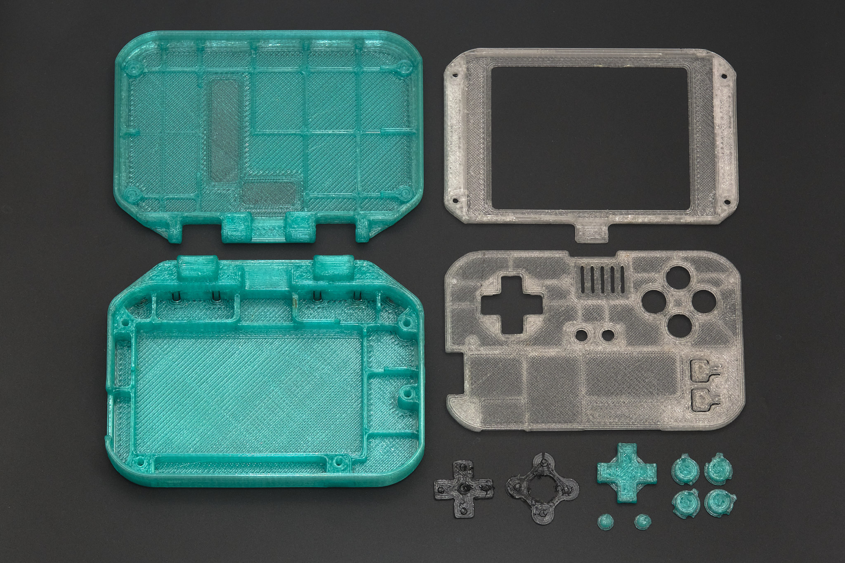
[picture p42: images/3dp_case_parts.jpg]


### all 3D printed parts for Altoids tin version

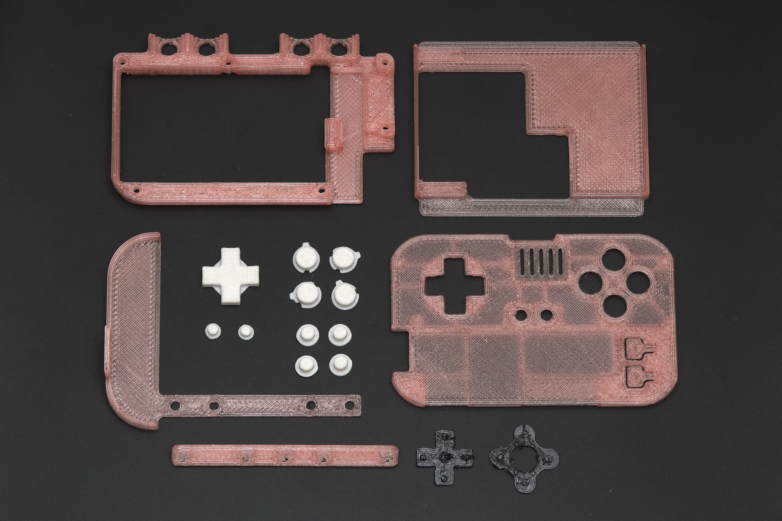
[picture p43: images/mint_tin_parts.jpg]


<small>All the parts shown in the photos were printed with a 0.6mm nozzle, using Bambu Lab PETG and PolyMaker PolyFlex TPU95.</small>

## note about practice boards

The latest version of the main PCB design includes two practice boards which must be broken off of the main PCB along the perforated lines. One of the boards has pads that match the Main PCB, with a second set of electrically connected pads that can be used to test continuity of the finished solder joints, and the second board has plated through holes matching the Raspberry Pi. They can be placed together as shown below and used to practice the soldering technique explained in the next section before actually soldering the Raspberry Pi to the main PCB.

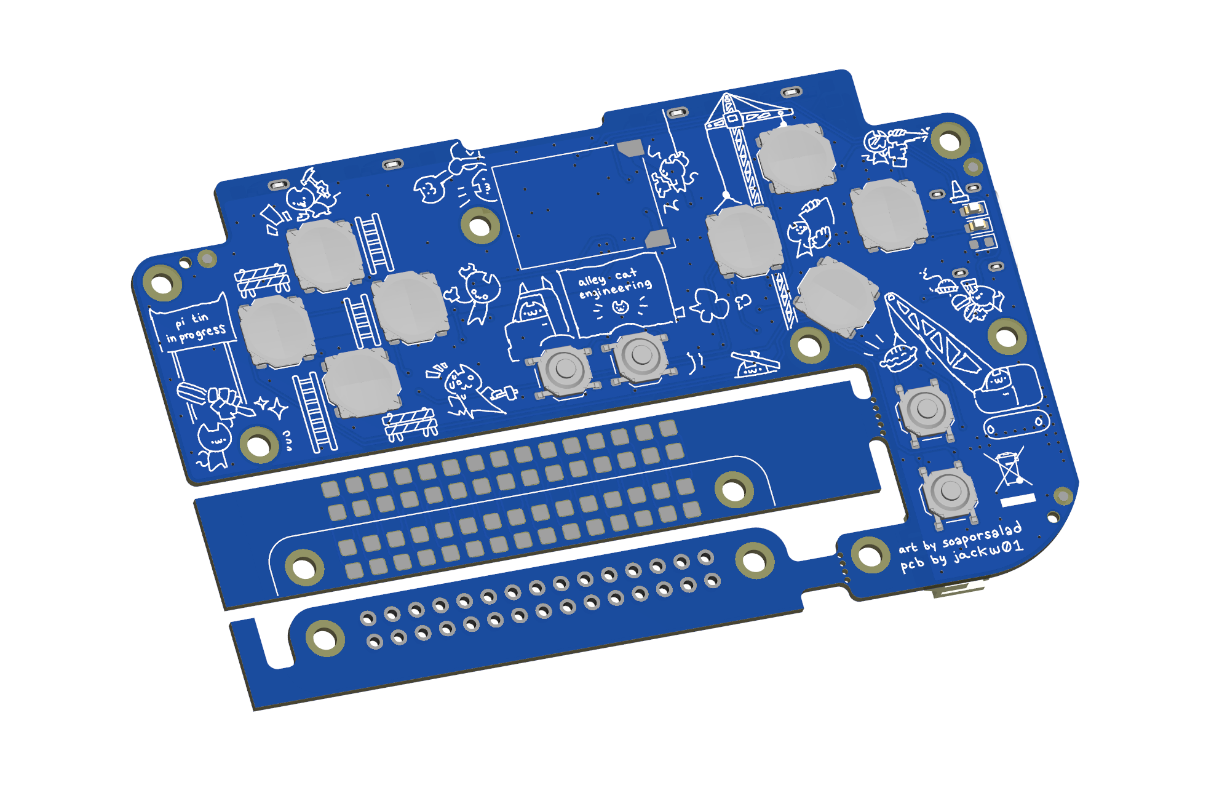
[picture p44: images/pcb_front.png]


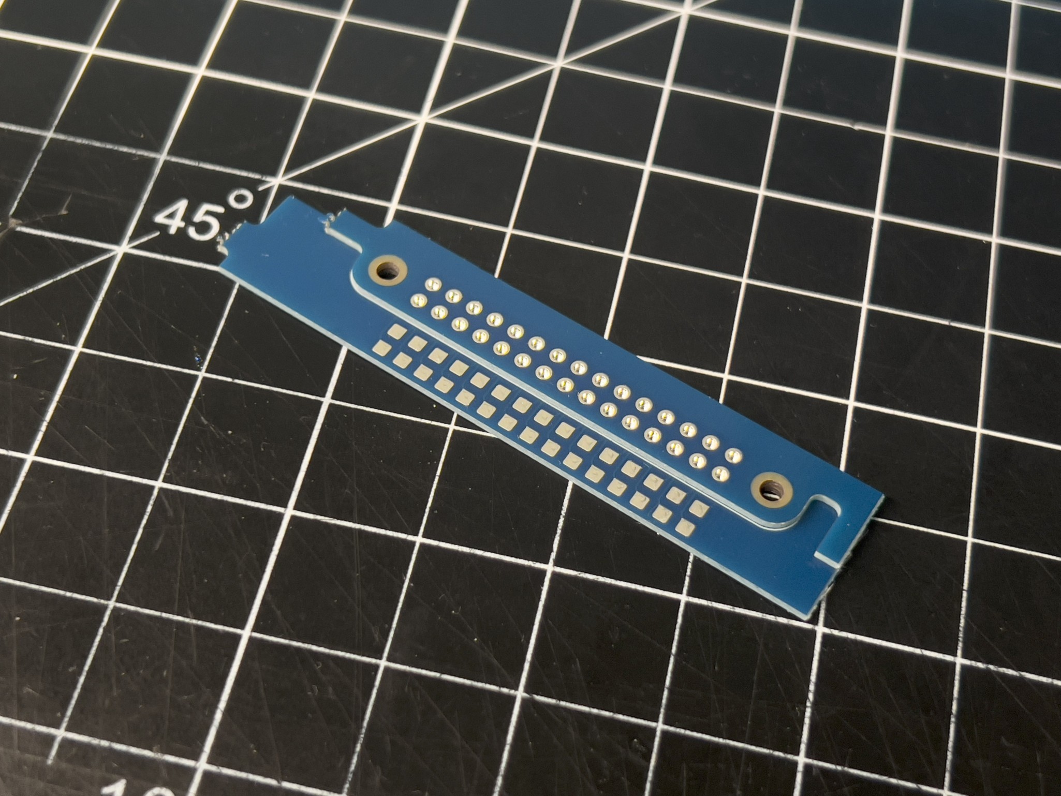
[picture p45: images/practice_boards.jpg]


## 1. solder the Raspberry Pi to the main PCB

**Important: Use a conical or chisel type soldering iron tip that is narrow enough to fit through one of the 40-pin header holes on the Raspberry Pi. If your tip is not narrow enough, it will be very difficult to solder the boards together correctly.**

Before starting, apply a thin layer of flux to the array of 40 square pads on the Main PCB.

Place the Raspberry Pi on the Main PCB as shown, with the blank side of the Pi facing upwards. Using small spring clamps or binder clips, clamp the PCBs together at the mounting hole next to Raspberry Pi pin 2 (circled) and the opposite corner of the Raspberry Pi, keeping the Raspberry Pi aligned with the outline on the Main PCB.

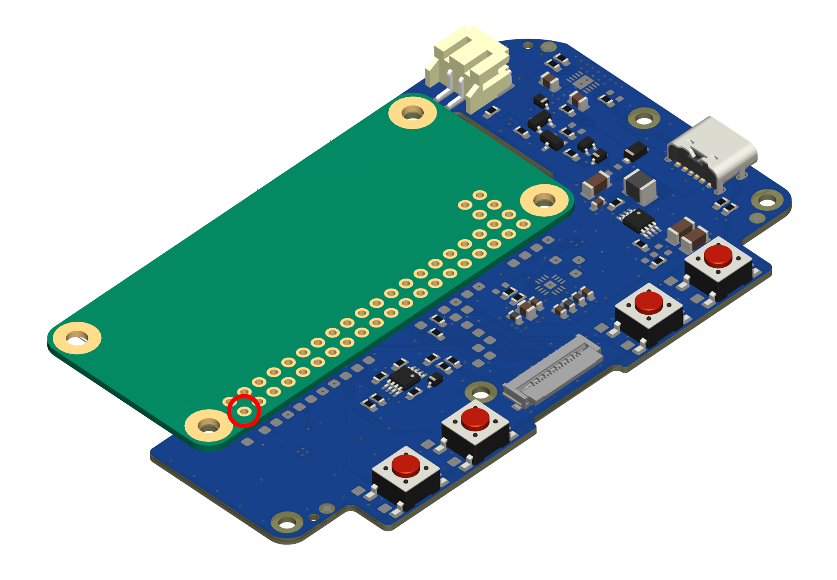
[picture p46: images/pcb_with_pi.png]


- Insert the soldering iron tip into the Pin 2 hole on the Raspberry Pi so that it makes contact with both the wall of the plated hole and the pad on the Main PCB.
- Wait 5-10 seconds for the pads to heat up, depending on the power of your soldering iron.
- Feed enough solder into the hole to partially fill it.
- Wait a few seconds for the solder to melt and stick to the walls of the hole and the pad on the Main PCB.
- Remove the soldering iron. If the solder does not form a smooth cup shape inside the hole, it is likely that it did not adhere to the pad on the Main PCB. Add some more flux and melt the solder again, holding the soldering iron in place for longer this time.

**Important: Be very careful handling the PCBs until more than a few of the Raspberry Pi pins have been soldered as it is easy to accidentally rip the pads off the Main PCB.**

Inspect the PCBs. If the Raspberry Pi is no longer aligned with the white outline on the main PCB or the two PCBs are not flush with each other where pin 2 is located, carefully reheat and reposition the solder joint. When the Pi is properly aligned, all three mounting holes should be centered and the white outline should be barely visible underneath the Pi.



**Important: The Raspberry Pi must be lined up exactly with the outline printed on the Main PCB. Otherwise, the PCB assembly may not fit correctly into the 3D printed parts. It is very difficult to correct any misalignment after more than one Raspberry Pi pad has been soldered, so it is critical to ensure that the PCBs are aligned after soldering the first pad.**

Once the first solder joint is complete, continue soldering the rest of the 40 through-hole pads on the Raspberry Pi to the Main PCB using the same steps used for Pin 2. We recommend soldering the opposite corner pad next while squeezing the PCBs together tightly to account for any warping of the PCBs, then soldering the remaining pads working from the outside of the array inwards.

**Important: The surface of the solder joints must be flush with the Raspberry Pi PCB. Any solder blobs or spikes that protrude from the surface may cause damage to the battery. Using enough flux should prevent this from being an issue.**

## 2. test the solder joints

Following the diagram below, use a multimeter to test for continuity between each test point and the corresponding pad on the Raspberry Pi to ensure the Pi is soldered correctly.

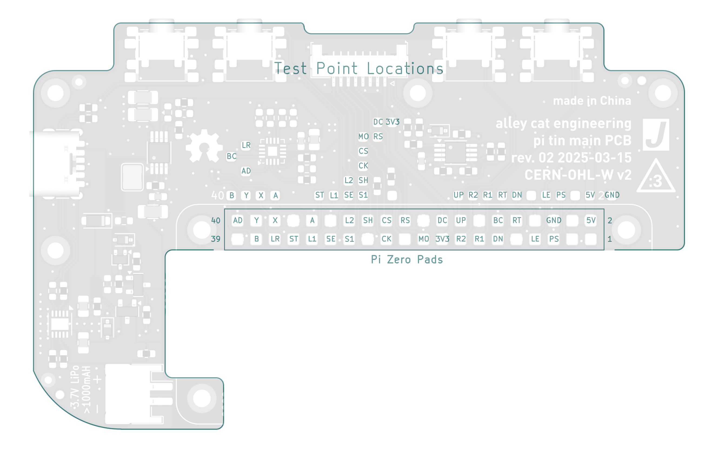
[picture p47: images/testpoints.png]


If any pads do not show continuity with their test point, add more flux to the solder joint and melt the solder again, holding the soldering iron tip inside the Raspberry Pi plated hole for at least 5 seconds.

## 3. display PCB assembly

Before inserting the display FPC (flexible printed circuit) into the connector on the Display PCB, ensure that the black retention tab on the connector (circled in the photos below) is in the open position (not pushed into the white connector housing). Insert the display FPC into the connector with the contacts facing up. It should not require any force to insert the FPC. If it does, the retention tab is likely not in the fully open position.

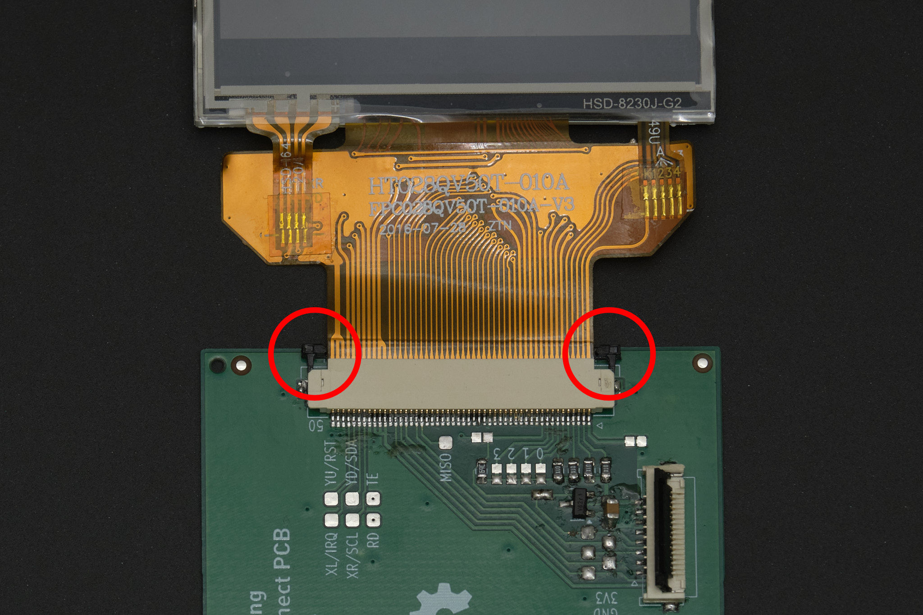
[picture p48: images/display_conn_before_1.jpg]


Carefully push in both sides of the retention tab at the same time until it is flush with the connector.

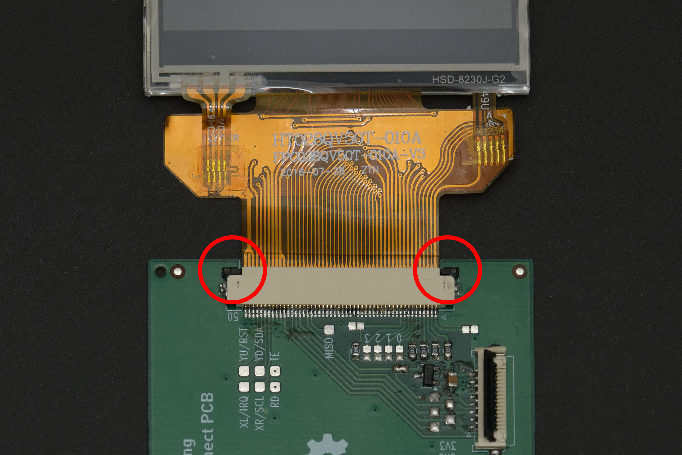
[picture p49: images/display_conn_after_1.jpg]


Lift up the black retention flap on the display interconnect cable connector. Insert the cable with the contacts facing down and flip down the retention flap. The cable should be held in securely.





## 4. front panel assembly

Insert the buttons into the back of the front panel as shown. The A/B/X/Y buttons can only be inserted one way. The buttons should fit loosely; if using DS Lite A/B/X/Y buttons, the flanges of the buttons may need to be carefully trimmed with a craft knife or flush cutters.



Insert the speaker into the front panel with the contacts facing upwards and to the left (away from the D-pad).

**Important: avoid touching the front surface of the speaker.**



If using 3D printed buttons, place the 3D printed TPU A/B/X/Y and D-pad membranes over the buttons as shown.



If using DS Lite buttons, insert the 3D printed TPU plugs into the A, B, X, Y, start, and select buttons and fit  the D-pad membrane over the peg at the center of the D-pad.



## 5. functional test

To prepare for software setup, connect the display cable to the Main PCB following the same procedure used to connect it to the Display PCB. Connect the battery to the connector at the corner of the Main PCB and ensure there is no SD card in the Raspberry Pi.



Connect the Main PCB to a power source using a USB-C cable. The green LED should illuminate to indicate that the battery is charging. If it does not, either there is something wrong with the USB-C cable or power source, or the PCB and/or battery is damaged.

*Note: The green LED indicates that the battery is charging. It turns off when the battery is fully charged. The orange LED indicates that the battery voltage is low. The Raspberry Pi will automatically shut down when the battery is critically low.*

Disconnect both the USB-C cable and the battery.

## next steps

Follow the [software setup guide](./software_setup) to install RetroPie on the Raspberry Pi and verify functionality.

Once you have installed RetroPie and verified that the hardware is working, continue to the final assembly guide for your build option.

- [final assembly - 3D printed case version](./3dp_assembly)
- [final assembly - Altoids tin version](./altoids_assembly)

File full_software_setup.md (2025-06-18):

# Pi Tin Full Software Installation Guide

To install and configure all required software "from scratch" on top of a clean install of RetroPie, follow the instructions below.

## 1. install RetroPie

Download the latest RetroPie image for Raspberry Pi 2/3/Zero 2 W [here](https://retropie.org.uk/download/). Extract the image from the .gz file and write it to a 8GB or larger MicroSD card using [Raspberry Pi Imager](https://www.raspberrypi.com/software/), [Etcher](https://etcher.balena.io/), or [Win32DiskImager](https://sourceforge.net/projects/win32diskimager/).

## 2. set up wifi and ssh for headless operation

After writing the SD card, eject and reinsert it to access the newly created boot partition. Create a file called `wpa_supplicant.conf` in the root directory of the boot partition with the contents below, replacing `SSID` and `PASSWORD` with your network name and password. You can add multiple networks by copying the `network={}` block. If you are outside of the United States, change `country=US` to your country's [ISO two-letter country code](https://en.wikipedia.org/wiki/List_of_ISO_3166_country_codes).

`wpa_supplicant.conf`

```conf
country=US
ctrl_interface=DIR=/var/run/wpa_supplicant GROUP=netdev
update_config=1

# RETROPIE CONFIG START
network={
    ssid="SSID"
    psk="PASSWORD"
}
# RETROPIE CONFIG END
```

Create an empty file called `ssh` or `ssh.txt` in the boot partition to enable SSH.

## 3. disable serial console

Edit `cmdline.txt` in the boot partition and remove `console=serial0,115200`. This will disable the hardware serial console, which is necessary since one of the serial pins is used for a gamepad button.

## 4. configure firmware options

Edit `config.txt` in the boot partition and add the content below to the end of the file.

```conf
# Enable GPIO power button functionality
dtoverlay=gpio-shutdown,gpio_pin=7,active_low=0,gpio_pull=up
dtoverlay=gpio-poweroff,gpiopin=3,active_low=1

# Lower GPU memory allocation
gpu_mem=128

# Disable UART
enable_uart=0

# Enable SPI with one chip select line (allow use of GPIO7)
dtoverlay=spi0-1cs,no_miso
```

## 5. connect via SSH

Insert the SD card and power up the Raspberry Pi. If the previous steps were done correctly, it should automatically connect to your WiFi network and you should be able to log in via SSH (`ssh pi@retropie.local`) using the default password `raspberry`.

We strongly recommend changing the user password since SSH and SMB are enabled. This can be done by running the `passwd` command on the Raspberry Pi.

## 6. configure startup behavior

Run the following commands to install required packages, download the startup script and button handlers, and configure them to run at boot, before the GPIOnext service starts.

```shell
sudo apt-get install pigpio python-pigpio python3-pigpio
sudo curl -o /usr/bin/shutdown_handler.py https://raw.githubusercontent.com/jackw01/pi-tin/main/software/shutdown_handler.py
sudo curl -o /usr/bin/brightness_control.py https://raw.githubusercontent.com/jackw01/pi-tin/main/software/brightness_control.py
sudo curl -o /usr/bin/pi_tin_startup.sh https://raw.githubusercontent.com/jackw01/pi-tin/main/software/pi_tin_startup.sh
sudo curl -o /etc/systemd/system/pi_tin_startup.service https://raw.githubusercontent.com/jackw01/pi-tin/main/software/pi_tin_startup.service
sudo chmod +x /usr/bin/shutdown_handler.py
sudo chmod +x /usr/bin/brightness_control.py
sudo chmod +x /usr/bin/pi_tin_startup.sh
sudo systemctl daemon-reload
sudo systemctl enable pi_tin_startup
sudo systemctl start pi_tin_startup
```

Run the following command to disable waiting for a network connection at boot.
```shell
sudo raspi-config nonint do_boot_wait 1
```

**Important: the startup shell script starts `pigpiod` with the `-t 0` argument to select the PWM clock peripheral. Running `pigpiod` without this argument will cause immediate physical damage to the speaker and/or audio amplifier.**

## 7. set up display

Use Adafruit's setup script to install and configure fbcp for the ILI9341 2.8" TFT display. Select the `Cupcade (horizontal screen)`option.

```shell
cd ~
curl -O https://raw.githubusercontent.com/adafruit/Raspberry-Pi-Installer-Scripts/master/pitft-fbcp.sh
sudo bash pitft-fbcp.sh
```

## 8. set up audio

Use Adafruit's setup script to MAX98357 I2S DAC. **Do not** enable the option to activate /dev/zero playback in the background.

```shell
cd ~
sudo apt-get update
sudo apt-get install python3-pip
pip3 install adafruit-python-shell
curl -O https://raw.githubusercontent.com/adafruit/Raspberry-Pi-Installer-Scripts/main/i2samp.py
sudo -E env PATH=$PATH python3 i2samp.py
```

Edit `/boot/config.txt` to change the line `dtoverlay=max98357a` to `dtoverlay=max98357a,no-sdmode=on` and change the line `dtparam=audio=on` to `#dtparam=audio=on`.

After rebooting, run `speaker-test -c2`. You should hear white noise from the speaker.

## 9. set up gamepad driver

Clone our fork of [GPIONext](https://github.com/jackw01/GPIOnext) (this fork supports using certain GPIO pins that the original does not) and download the config file. Run the install script and enter `n` when asked to run the configuration manager, then start the GPIOnext daemon. The EmulationStation UI should now respond to button presses.

```shell
cd ~
git clone https://github.com/jackw01/GPIOnext.git
curl -o GPIOnext/config/config.db https://raw.githubusercontent.com/jackw01/pi-tin/main/software/config.db
bash GPIOnext/install.sh
gpionext start
```

## 10. update RetroPie and OS packages

Run the RetroPie setup script.

```shell
sudo ~/RetroPie-Setup/retropie_setup.sh
```

Follow the prompts and select `Update` to update installed packages. Select `Yes` on the prompt asking to update OS packages. This will take a while.

## 11. install RetroPie theme

To install a theme that works better on small displays, first run the RetroPie setup script.

```shell
sudo ~/RetroPie-Setup/retropie_setup.sh
```

Select `Configuration / Tools > esthemes > Install anthonycaccese/tft`. Exit the setup script. Run the command below to create the EmulationStation settings file, which shouldn't exist yet, and set the theme to `tft`.

```shell
cd ~
curl -o .emulationstation/es_settings.cfg https://raw.githubusercontent.com/jackw01/pi-tin/main/software/es_settings.cfg
```

## 12. configure RetroArch

For more seamless operation, we recommend configuring RetroArch to automatically save the game state when exiting and load the saved state when starting. This setting can be changed later for individual ROMs. To do this, edit `/opt/retropie/configs/all/retroarch.cfg` and change the lines

```conf
savestate_auto_load = ...
savestate_auto_save = ...
```

to

```conf
savestate_auto_load = "true"
savestate_auto_save = "true"
```

When combined with the Pi Tin shutdown handler script, this change will allow the state to be automatically saved before the system shuts down.

## 13. set volume

Run `amixer set PCM 50%` to set the volume to a more reasonable level.

## additional notes

For now, do not install `pulseaudio` to use Bluetooth audio devices. In testing we found that it interacts poorly with the MAX98357 I2S DAC+amp and causes it to draw so much current that it triggers the battery protection circuit.

## sources

- [Running OpenGL-based Games & Emulators on Adafruit PiTFT Displays](https://learn.adafruit.com/running-opengl-based-games-and-emulators-on-adafruit-pitft-displays/)
- [Adafruit MAX98357 I2S Class-D Mono Amp](https://learn.adafruit.com/adafruit-max98357-i2s-class-d-mono-amp/overview)

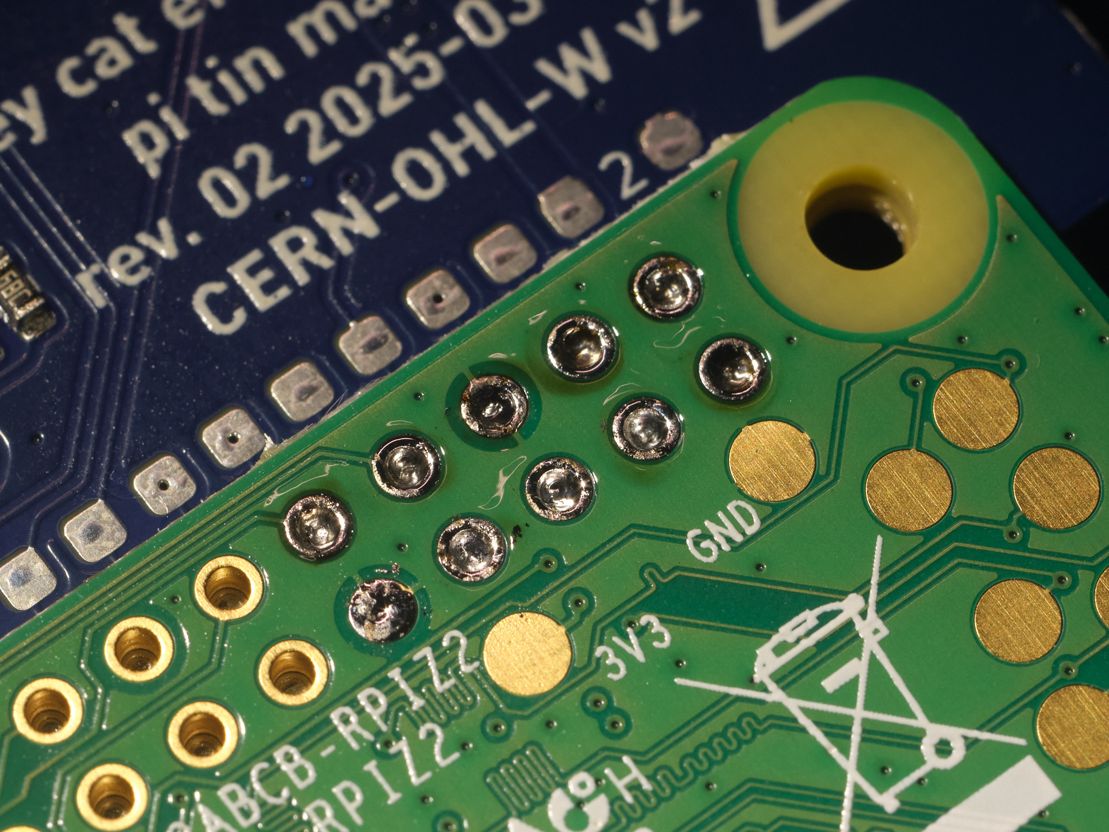
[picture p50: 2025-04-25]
images/solder_example.jpg

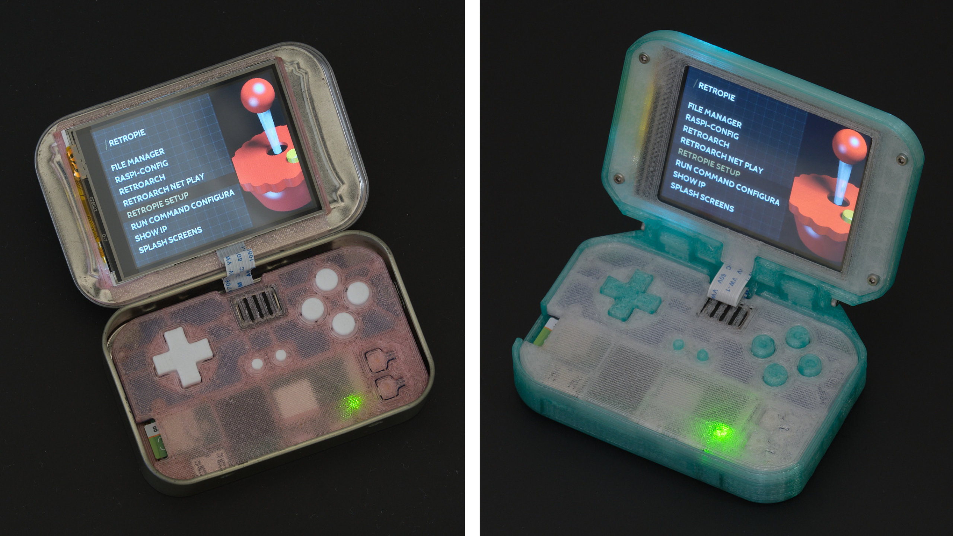
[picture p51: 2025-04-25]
images/build_options_2.jpg

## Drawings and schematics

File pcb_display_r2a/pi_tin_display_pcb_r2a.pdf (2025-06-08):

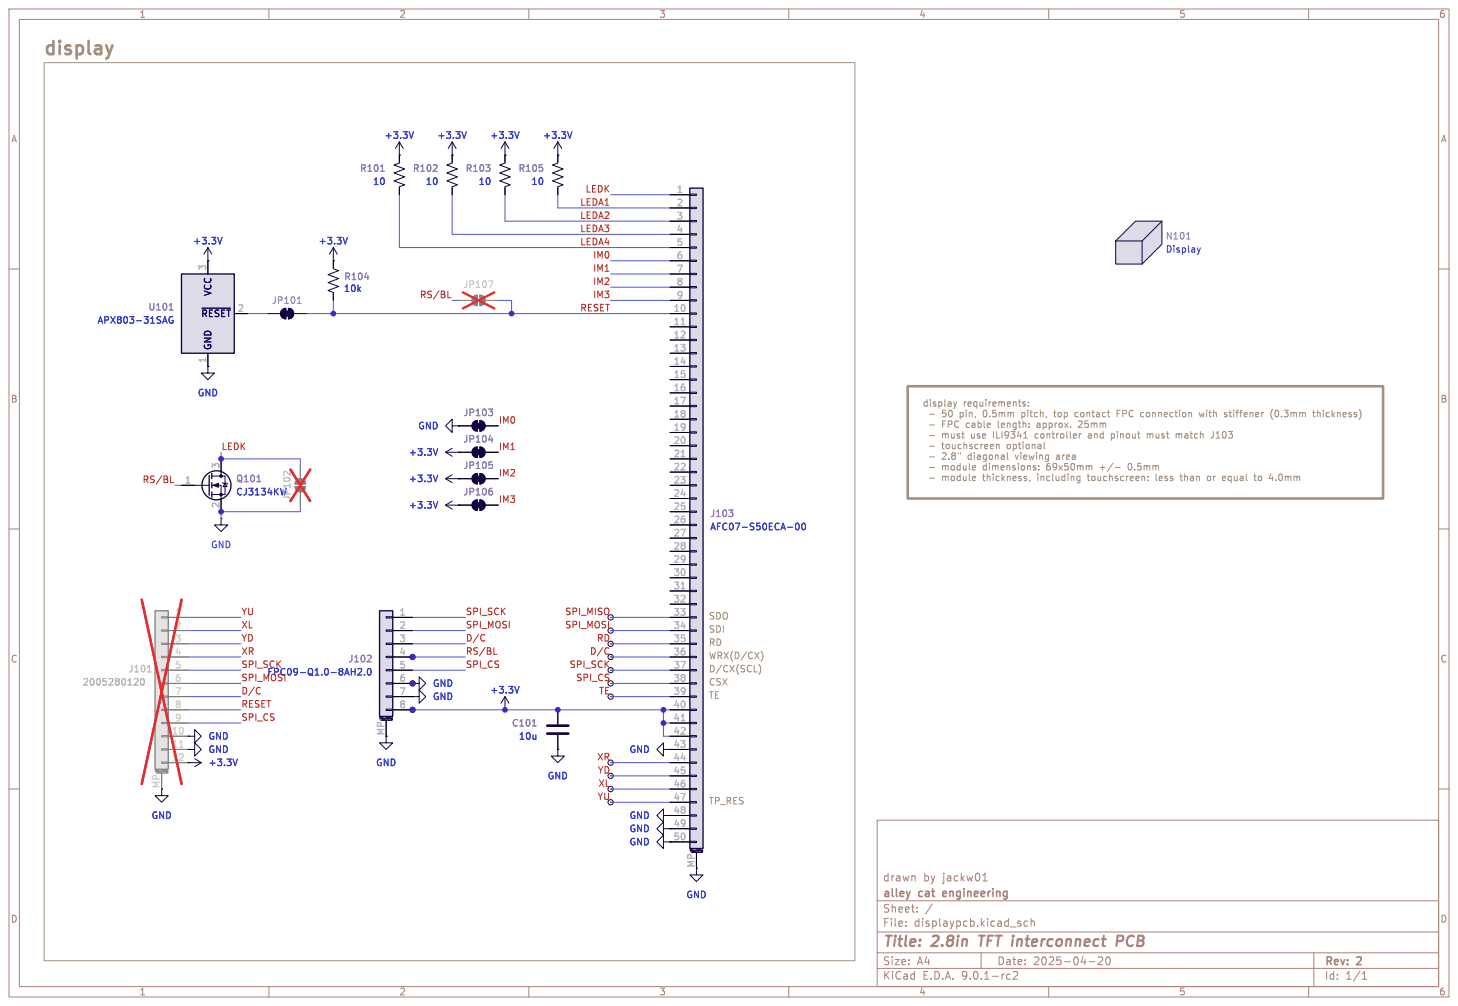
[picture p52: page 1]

TECSX D/CX(SCL) TP_RES RD display
10 GND

- FPC cable length: approx. 25mm

drawn by jackw01
File: displaypcb.kicad_sch Sheet: / alley cat engineering

Id: 1/1 Title: 2.8in TFT interconnect PCB

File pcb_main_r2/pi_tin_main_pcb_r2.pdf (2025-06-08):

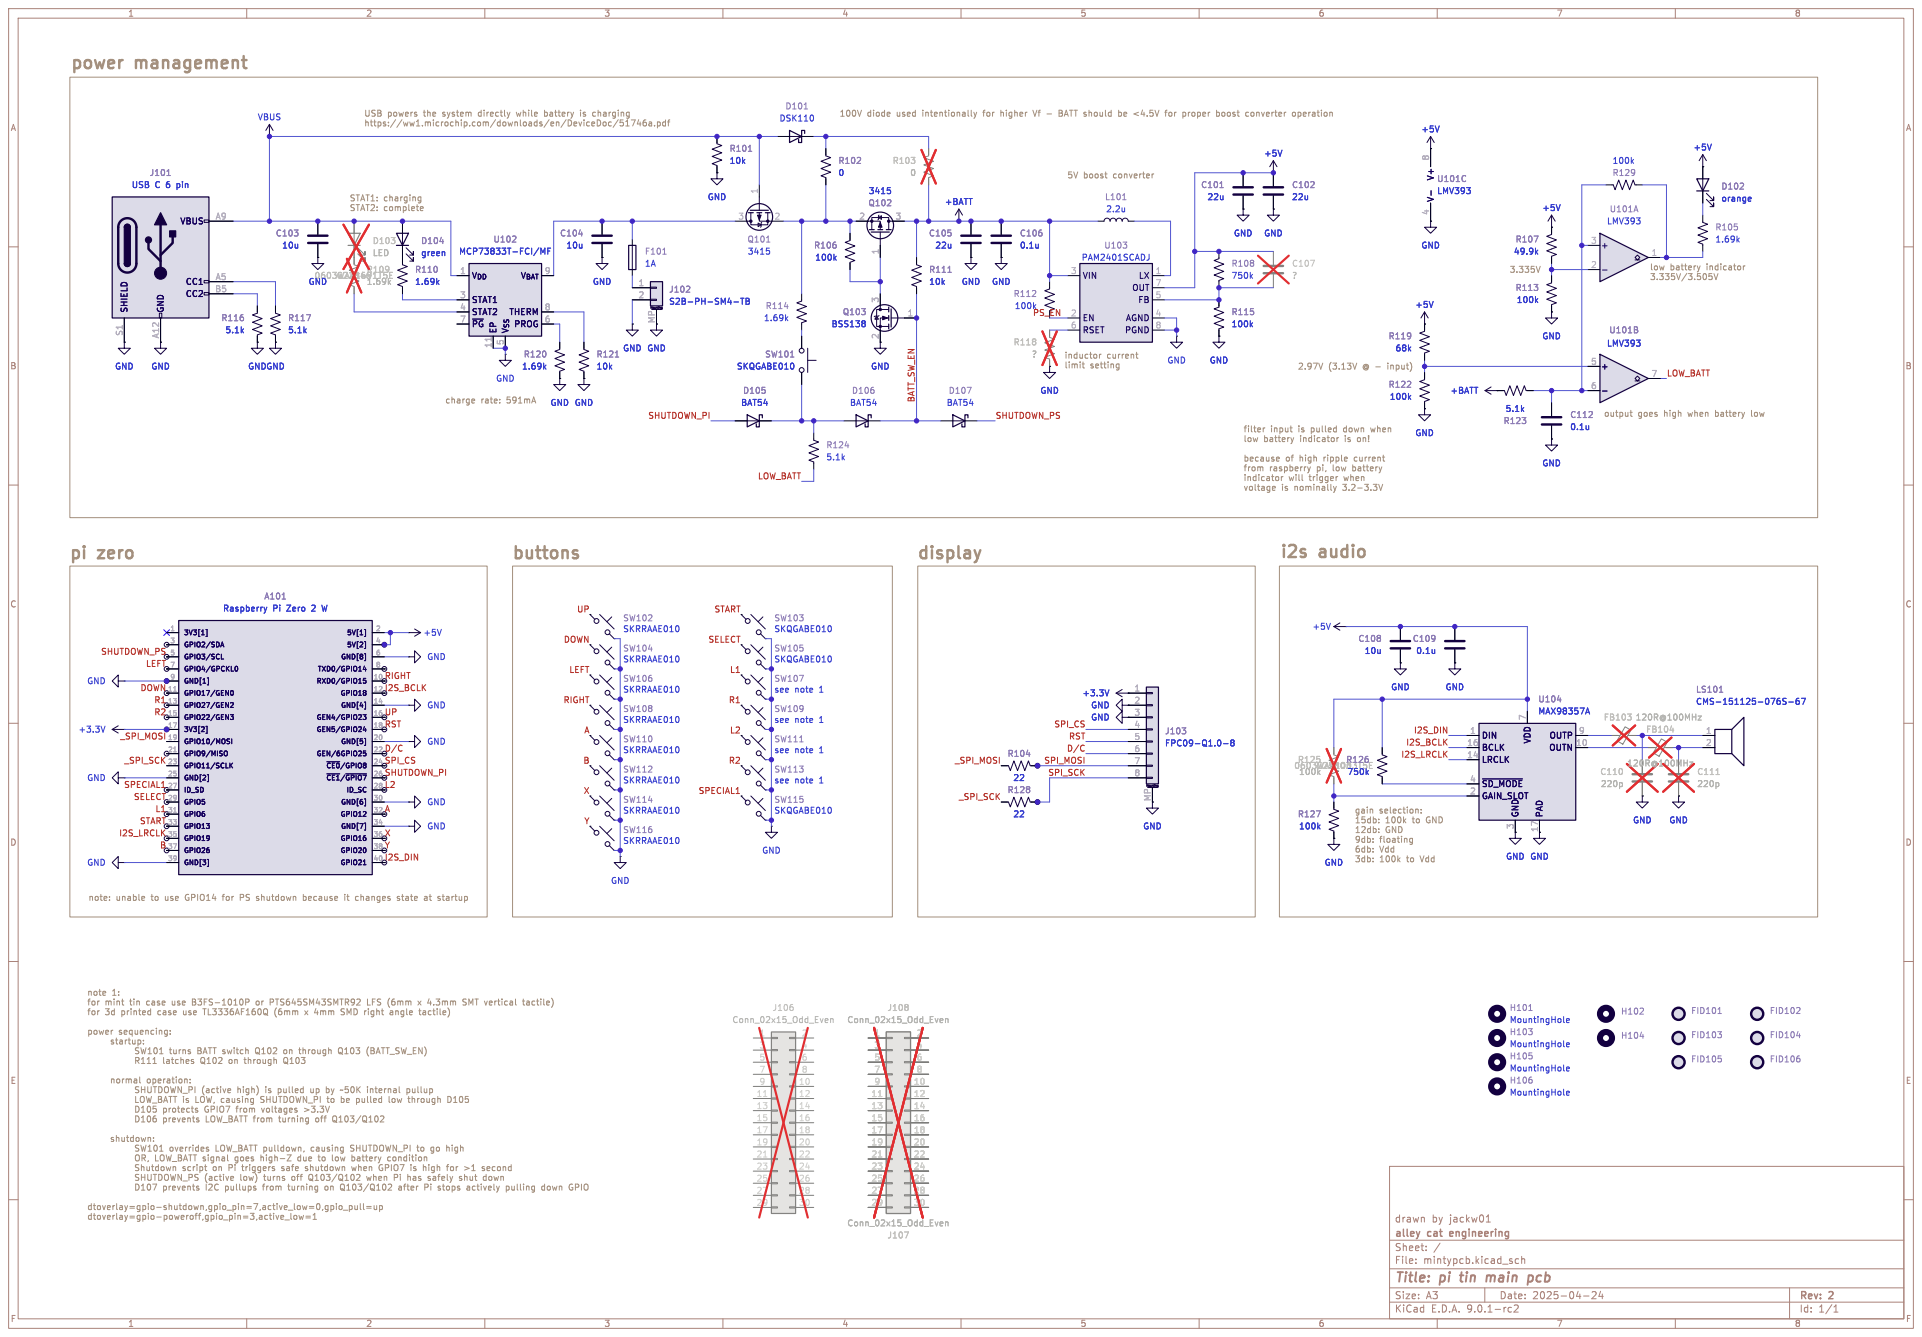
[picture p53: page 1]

https://ww1.microchip.com/downloads/en/DeviceDoc/51746a.pdf

10u GND
low battery indicator 3.335V/3.505V buttons

output goes high when battery low

filter input is pulled down when

3V3[2] 17 GPIO10/MOSI 19 GPIO9/MISO 21 GPIO11/SCLK 23 GND[2] 25

gain selection: 15db: 100k to GND

note: unable to use GPIO14 for PS shutdown because it changes state at startup

dtoverlay=gpio-shutdown,gpio_pin=7,active_low=0,gpio_pull=up
dtoverlay=gpio-poweroff,gpio_pin=3,active_low=1

File: mintypcb.kicad_sch Sheet: / alley cat engineering

Id: 1/1 Title: pi tin main pcb

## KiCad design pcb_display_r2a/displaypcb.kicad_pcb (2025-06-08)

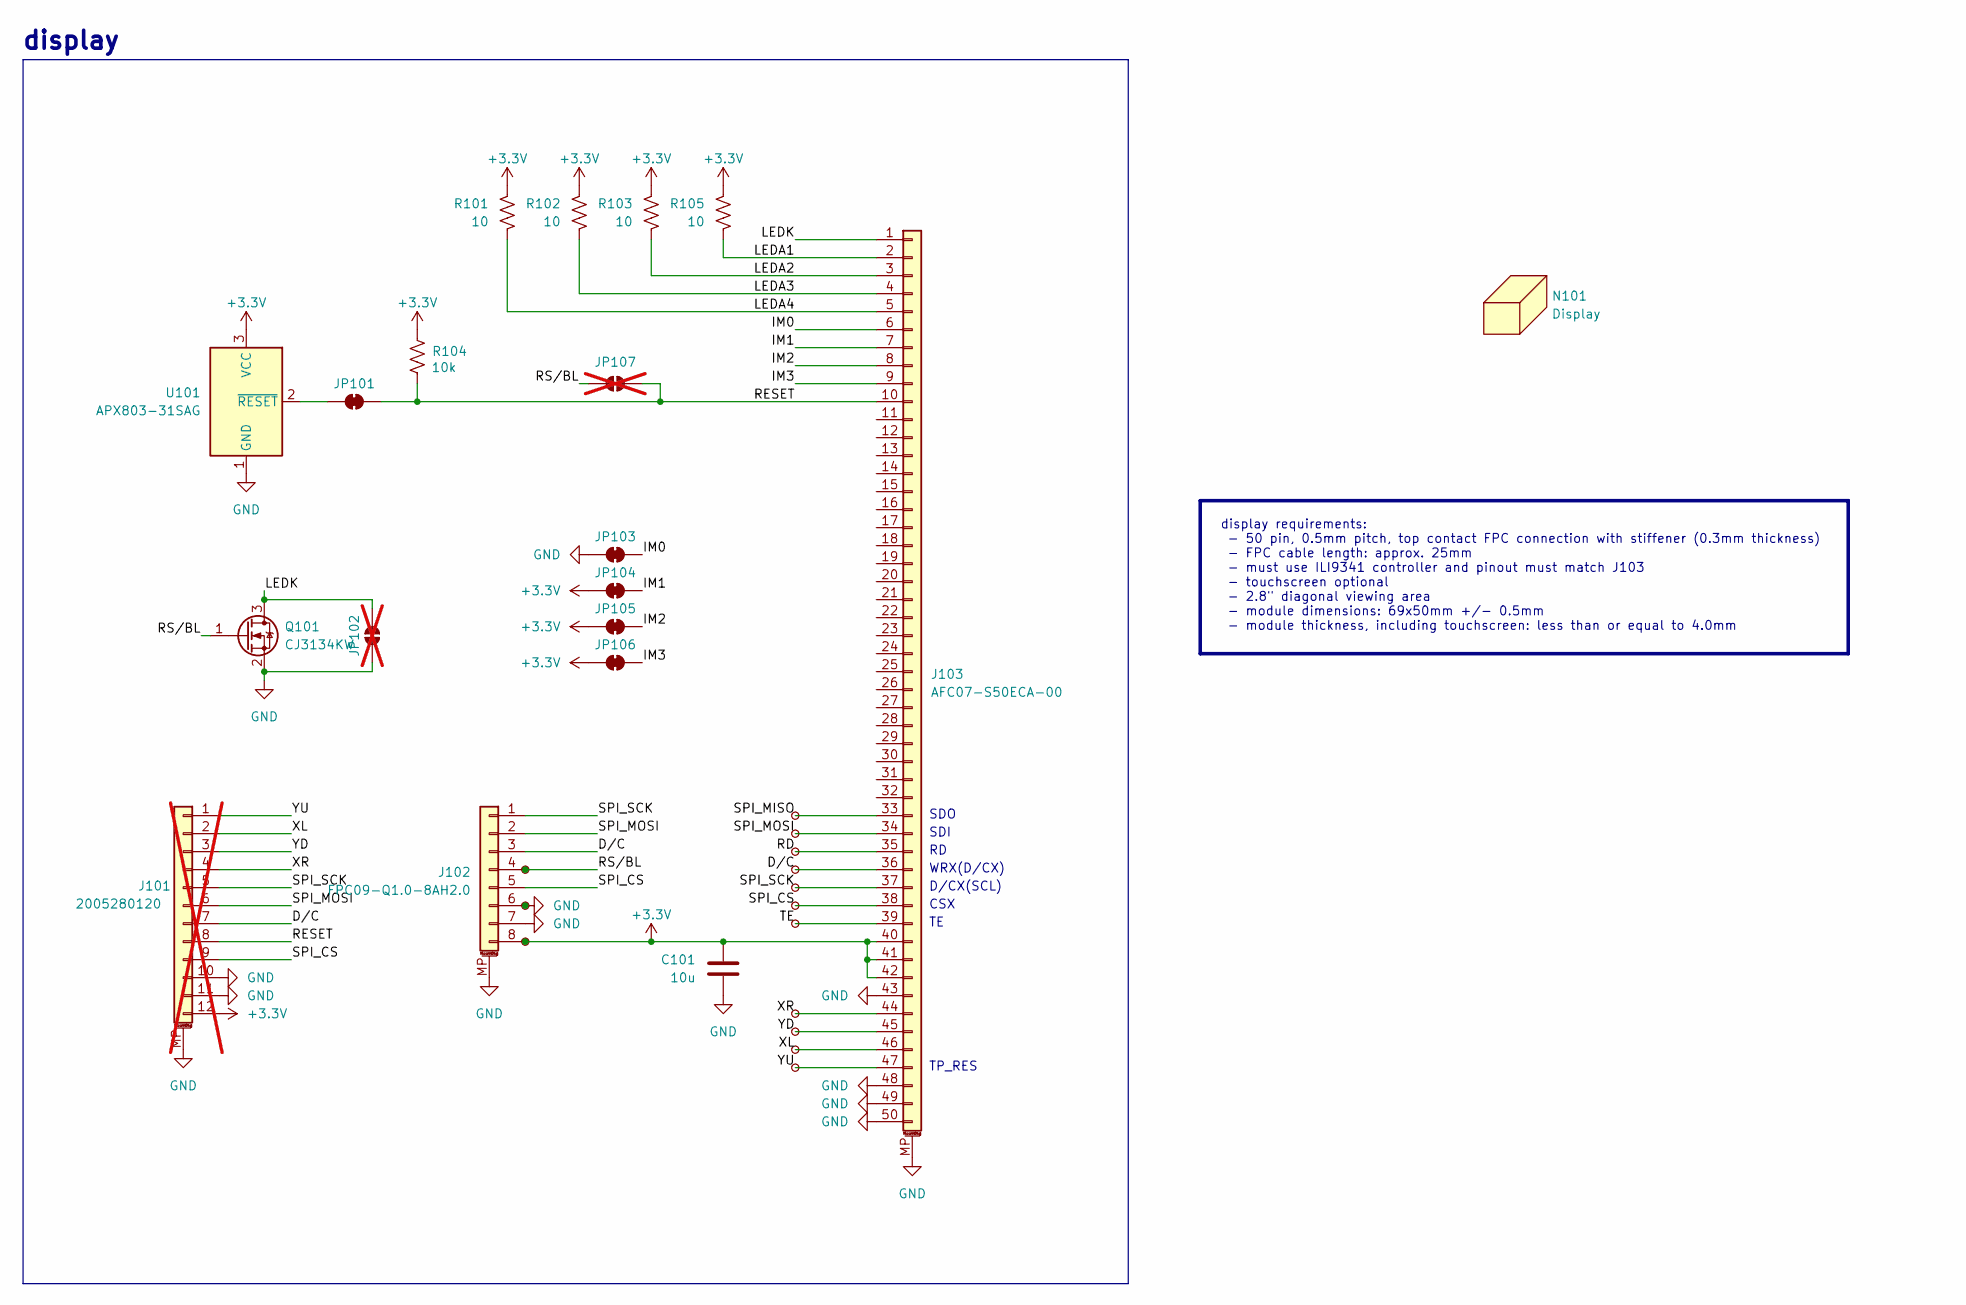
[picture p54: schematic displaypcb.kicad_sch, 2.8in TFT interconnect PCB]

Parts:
C101: 10u; C_0805_2012Metric; MPN CL21B106KPQNNNE; LCSC C32635
J101: 2005280120; Molex_200528-0120_1x12-1MP_P1.00mm_Horizontal; MPN 2005280120; not fitted
J102: FPC09-Q1.0-8AH2.0; XYECONN_FPC09-Q1.0-8AH2.0; MPN FPC09-Q1.0-8AH2.0; LCSC C19269923
J103: AFC07-S50ECA-00; Jushuo_AFC07-S50ECA-00; MPN AFC07-S50ECA-00; LCSC C262650
JP101, JP103, JP104, JP105, JP106: SolderJumper_2_Bridged; R_0402_1005Metric_bridged
JP102, JP107: SolderJumper_2_Open; R_0402_1005Metric; not fitted
N101: Display; TFT_2.8in_ILI9341
Q101: CJ3134KW; SOT-323_SC-70; MPN CJ3134KW; LCSC C110101
R101, R102, R103, R105: 10; R_0603_1608Metric; MPN 0603WAF100JT5E; LCSC C22859
R104: 10k; R_0603_1608Metric; MPN 0603WAF1002T5E; LCSC C25804
TP101, TP102, TP103, TP104, TP105, TP106, TP107, TP108, TP109, TP110, TP111, TP112, TP113, TP114: TestPoint_Small; TestPoint_Pad_D1.5mm
U101: APX803-31SAG; SOT-23; MPN APX803-31SAG-7; LCSC C460552

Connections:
+3.3V: C101.1, J101.12, J102.8, J103.40, J103.41, J103.42, JP104.1 (A), JP105.1 (A), JP106.1 (A), R101.2, R102.2, R103.2, R104.1, R105.2, TP102.1, U101.3 (VCC)
/D/C: J101.7, J102.3, J103.36, TP107.1
/IM0: J103.6, JP103.2 (B)
/IM1: J103.7, JP104.2 (B)
/IM2: J103.8, JP105.2 (B)
/IM3: J103.9, JP106.2 (B)
/LEDA1: J103.2, R105.1
/LEDA2: J103.3, R103.1
/LEDA3: J103.4, R102.1
/LEDA4: J103.5, R101.1
/LEDK: J103.1, JP102.2 (B), Q101.3 (D)
/RD: J103.35, TP106.1
/RESET: J101.8, J103.10, JP101.2 (B), JP107.2 (B), R104.2
/RS/BL: J102.4, JP107.1 (A), Q101.1 (G), TP103.1
/SPI_CS: J101.9, J102.5, J103.38, TP109.1
/SPI_MISO: J103.33, TP104.1
/SPI_MOSI: J101.6, J102.2, J103.34, TP105.1
/SPI_SCK: J101.5, J102.1, J103.37, TP108.1
/TE: J103.39, TP110.1
/XL: J101.2, J103.46, TP113.1
/XR: J101.4, J103.44, TP111.1
/YD: J101.3, J103.45, TP112.1
/YU: J101.1, J103.47, TP114.1
GND: C101.2, J101.10, J101.11, J101.MP (MountPin), J102.6, J102.7, J102.MP (MountPin), J103.43, J103.48, J103.49, J103.50, J103.MP (MountPin), JP102.1 (A), JP103.1 (A), Q101.2 (S), TP101.1, U101.1 (GND)
unnamed: JP101.1 (A), U101.2 (~RESET)

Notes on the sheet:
display
CSX
WRX(D/CX)
D/CX(SCL)
SDI
TP_RES
SDO
display requirements: - 50 pin, 0.5mm pitch, top contact FPC connection with stiffener (0.3mm thickness) - FPC cable length: approx. 25mm - must use ILI9341 controller and pinout must match J103 - touchscreen optional - 2.8" diagonal viewing area - module dimensions: 69x50mm +/- 0.5mm - module thic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

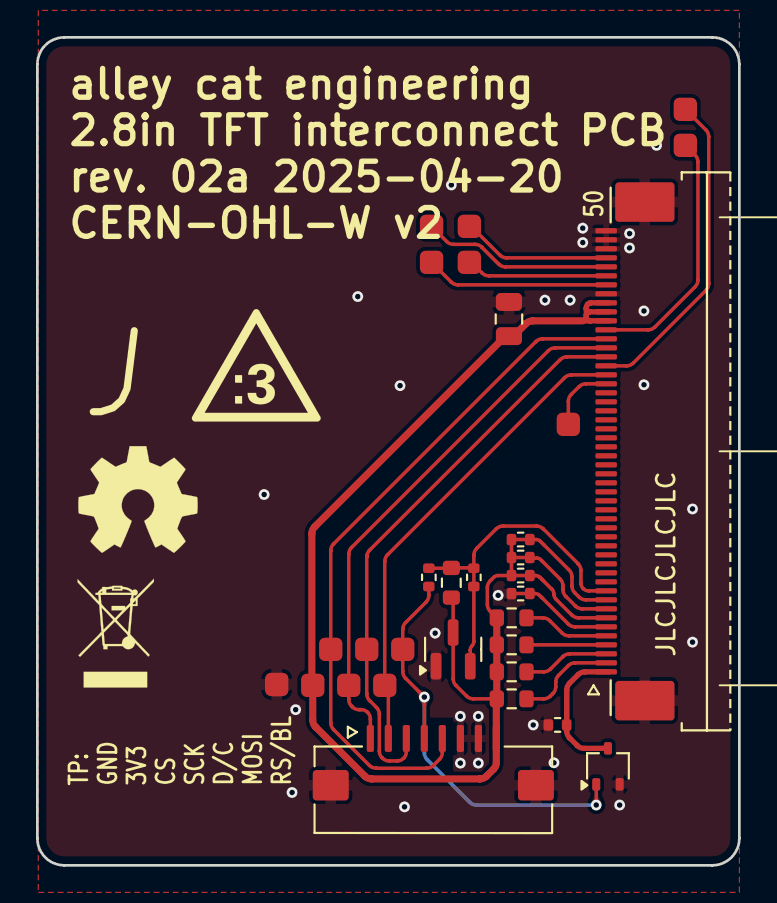
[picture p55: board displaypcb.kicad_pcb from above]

Board: 2 copper layers, 39.0 x 46.0 mm, 32 parts (1 on the bottom side), 25 nets.

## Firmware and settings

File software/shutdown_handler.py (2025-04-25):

#!/usr/bin/python3

import RPi.GPIO as GPIO
import time
import os
import sys

pin_button = 7

GPIO.setmode(GPIO.BCM)
GPIO.setup(pin_button, GPIO.IN, pull_up_down=GPIO.PUD_UP)

def main():
    while (True):
        if GPIO.input(pin_button):
            time.sleep(0.5)
            if GPIO.input(pin_button):
                os.system("echo 1 >/sys/class/leds/led0/brightness")
                # stop retroarch first to allow it to save state
                os.system("killall -s SIGTERM retroarch")
                os.system("killall -s SIGTERM emulationstatio")
                os.system("killall -s SIGTERM emulationstation")
                time.sleep(3)
                # stop gpionext (if this is not done it can cause system to hang for 2 minutes before shutdown if a button is held down at shutdown time)
                os.system("systemctl kill gpionext")
                # stop pigpiod (if this is not done it can cause system to randomly hang before shutdown)
                os.system("killall -s SIGKILL pigpiod")
                time.sleep(0.5)
                os.system("shutdown now -h")
        time.sleep(0.3)

if __name__ == "__main__":
    main()
    sys.exit(0)

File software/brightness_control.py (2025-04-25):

#!/usr/bin/python3

from evdev import InputDevice, categorize, ecodes, list_devices
import pigpio
import threading
import time
import atexit
import os

device = False

while device == False:
    devices = [InputDevice(path) for path in list_devices()]
    if (len(devices) > 0):
        device_path = devices[0].path
        device = InputDevice(device_path)
    time.sleep(1)

file_path = "/etc/brightness.txt"
pin_backlight = 24
brightness_max = 100
brightness_step = 2
current_brightness = brightness_max
adjusting = False
timestep_initial = 0.5
timestep_fast = 0.08
timestep = timestep_initial

if os.path.exists(file_path):
    with open(file_path, "r") as f:
        current_brightness = int(f.read())

pi = pigpio.pi()
pi.set_mode(pin_backlight, pigpio.OUTPUT)
pi.set_PWM_range(pin_backlight, brightness_max)
pi.set_PWM_frequency(pin_backlight, 800)
pi.set_PWM_dutycycle(pin_backlight, max(current_brightness * current_brightness // brightness_max, 1))

def adjust_brightness(first, delta):
    global current_brightness, adjusting, timestep
    if first == True:
        adjusting = True
        timestep = timestep_initial
    if adjusting == False:
        return
    current_brightness += delta
    if current_brightness < brightness_step:
        current_brightness = brightness_step
    elif current_brightness > brightness_max:
        current_brightness = brightness_max
    pi.set_PWM_dutycycle(pin_backlight, max(current_brightness * current_brightness // brightness_max, 1))
    timer = threading.Timer(timestep, adjust_brightness, [False, delta])
    if timestep == timestep_initial:
        timestep = timestep_fast
    timer.start()

def save():
    with open(file_path, "w") as f:
        f.write(str(current_brightness))

atexit.register(save)

hotkey_state = 0

for event in device.read_loop():
    if event.type == ecodes.EV_KEY:
        key_event = categorize(event)
        if hotkey_state == key_event.key_down and key_event.keystate == key_event.key_down:
            if event.code == ecodes.BTN_TL2:
                adjust_brightness(True, -brightness_step)
            elif event.code == ecodes.BTN_TR2:
                adjust_brightness(True, brightness_step)
        if event.code in [ecodes.BTN_TRIGGER_HAPPY2, ecodes.BTN_TL2, ecodes.BTN_TR2] and key_event.keystate == key_event.key_up:
            adjusting = False
        if event.code == ecodes.BTN_TRIGGER_HAPPY2:
            hotkey_state = key_event.keystate

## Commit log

2025-03-19 add pcb and 3d files
    [displaypcb-B_Cu.gbl, displaypcb-B_Mask.gbs, displaypcb-B_Paste.gbp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]
2025-06-08 production 3D and PCB files
    [displaypcb-B_Cu.gbl, displaypcb-B_Mask.gbs, displaypcb-B_Paste.gbp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]
2025-06-14 update p001 rear housing stl for better printability with 0.6mm nozzle

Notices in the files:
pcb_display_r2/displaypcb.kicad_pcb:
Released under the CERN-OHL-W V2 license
